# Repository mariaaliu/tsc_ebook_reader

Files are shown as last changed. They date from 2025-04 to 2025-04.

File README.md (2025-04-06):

## Aliu Maria-Denisa
#### 335CC
<br><br>

## Descriere generală
Acest proiect reprezintă un eBook Reader minimalist, denumit **OpenBook**, construit pe baza platformei **ESP32-C6** și echipat cu un ecran e-paper de **7.5 inch**, o baterie Li-Po, încărcare prin USB-C și butoane fizice pentru control.

Dispozitivul este proiectat să fie eficient energetic și ușor de utilizat, având o interfață simplă controlată prin GPIO-uri, cu funcții de afișare a textelor pentru o experiență de e-reading optimă.

---

<br><br>

## Cuprins
- [Specificații](#specificații)
- [Pași de implementare](#pași-de-implementare)
- [Diagramă Bloc](#diagramă-bloc)
- [BOM (Bill Of Materials)](#bom-bill-of-materials)
- [Descrierea hardware – Conexiuni și Funcționalitate](#descrierea-hardware--conexiuni-și-funcționalitate)
- [Pinout ESP32-C6](#pinout-esp32-c6)
- [Estimare Consum](#estimare-consum)
- [Vederi ale Prototipului](#vederi-ale-prototipului)

---

#### Specificații

- **MCU**: ESP32-C6 (Wi-Fi 6, BLE, RISC-V)
- **Ecran**: 7.8" E-paper
- **Stocare**: Slot microSD
- **Conectivitate**: Qwiic, USB-C
- **Senzori**: BME680 (temperatură, umiditate, gaz, presiune)
- **Alimentare**: Baterie Li-Po 3.7V, încărcare prin USB-C
- **RTC**: extern pentru consum redus în deep sleep
- **Control**: 3 butoane + LED

---
#### Pași de implementare:

- realizarea schemei electrice
- poziționarea pieselor pe PCB 2D
- realizarea modelului 3D
- simularea încadrării pieselor în carcasa finală
- prezentarea produsului final simulat
  
---

## Diagramă Bloc

```mermaid
graph TD;
    
    USB["USB-C Connector & ESD Protection"] -->|VBUS| CHG
    BATT["Li-Po Battery"] -->|VBAT| CHG["Battery Charging Controller (MCP73831)"]
    USB -->|VBUS pass-through| LDO["LDO Voltage Regulator (XC6220)"]
    USB -->|USB| ESP["ESP32-C6 MICROCONTROLLER Wi-Fi (MCU Central)"]
    CHG -->|VBAT| LDO
    LDO -->|3.3V| ESP["ESP32-C6 MICROCONTROLLER Wi-Fi (MCU Central)"]

    ESP -->|I2C| RTC["RTC Module (DS3231SN)"]
    ESP -->|I2C| BME["Environmental Sensor (BME680)"]

    ESP -->|SPI| FLASH["External NOR Flash (W25Q512)"]
    ESP -->|SPI| EPD_HEADER["E-Paper Display Header"]
    ESP -->|SPI| SD["MicroSD Card"]
    ESP -->|GPIO| BUTTONS["BOOT, CHANGE, RESET Buttons"]
    ESP -->|GPIO| VSUP["Voltage Supervisor + Reset/Boot IO"]

    EPD_HEADER -->|Power, SPI| EPD_DRIVER["E-Paper Drive Circuit"]
    EPD_DRIVER -->|Type Config| DISP_SEL["Display Type Selector"]
    EPD_DRIVER -->|High Voltage| EPD_POW["EPD Power Circuit"]

    I2C_CONN["Qwiic / Stemma QT"] -->|I2C| ESP
    BAT_LVL["Battery Charge Level"] -->|I2C| ESP
    SERCOM["RX/TX Serial Communication"] --> ESP
```

## BOM (Bill Of Materials)

| Componentă | Proptietăți | Package | Link Purchase | Datasheet | 
|---|---|---|---|---|
| BOOT_BUTTON | BUTTON_CUSYOMV1 | MYBUTTON | https://industry.panasonic.com/global/en/products/control/switch/light-touch/number/evqpuj02k | https://www.es.co.th/Schemetic/PDF/EVQPUX02K.PDF|
| C1 | 100nF | ESP32_WROVER_EAGLE-LTSPICE_C0402 | https://componentsearchengine.com/part-view/CC0402MRX5R5BB106/YAGEO | https://www.farnell.com/datasheets/2167237.pdf|
| C10 | 100nF | ESP32_WROVER_EAGLE-LTSPICE_C0402 | https://componentsearchengine.com/part-view/CC0402MRX5R5BB106/YAGEO | https://www.farnell.com/datasheets/2167237.pdf|
| C10_SUPERCAP | CPH3225A | CAPCP3225X100N  | https://www.snapeda.com/parts/CPH3225A/Seiko+Instruments/view-part/?ref=eda | https://www.eaton.com/content/dam/eaton/products/electronic-components/resources/data-sheet/eaton-xt-supercapacitors-cylindrical-cells-data-sheet.pdf|
| C1_BAT | 4.7uF | ESP32_WROVER_EAGLE-LTSPICE_C0402 | https://componentsearchengine.com/part-view/CC0402MRX5R5BB106/YAGEO | https://www.datasheets.com/part-details/ctc4-c-4-7uf-20--25v-exxelia-group-407015684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|
| C1_BAT1 | 4.7uF | ESP32_WROVER_EAGLE-LTSPICE_C0402 | https://componentsearchengine.com/part-view/CC0402MRX5R5BB106/YAGEO | https://www.datasheets.com/part-details/ctc4-c-4-7uf-20--25v-exxelia-group-407015684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|
| C1_BAT2 | 4.7uF | ESP32_WROVER_EAGLE-LTSPICE_C0402 | https://componentsearchengine.com/part-view/CC0402MRX5R5BB106/YAGEO | https://www.datasheets.com/part-details/ctc4-c-4-7uf-20--25v-exxelia-group-407015684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|
| C2 | 100nF | ESP32_WROVER_EAGLE-LTSPICE_C0402 | https://componentsearchengine.com/part-view/CC0402MRX5R5BB106/YAGEO | https://www.farnell.com/datasheets/2167237.pdf|
| C2_BAT | 4.7uF | ESP32_WROVER_EAGLE-LTSPICE_C0402 | https://componentsearchengine.com/part-view/CC0402MRX5R5BB106/YAGEO | https://www.datasheets.com/part-details/ctc4-c-4-7uf-20--25v-exxelia-group-407015684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|
| C3 | 100uF | RCL_CT3528 | https://eu.mouser.com/ProductDetail/KYOCERA-AVX/F910J107MBAAJ6?qs=PqoDHHvF649LraCA%2FjeGXg%3D%3D | https://www.farnell.com/datasheets/2167237.pdf|
| C4 | 4.7uF/25V | ESP32_WROVER_EAGLE-LTSPICE_C0402 | https://componentsearchengine.com/part-view/CC0402MRX5R5BB106/YAGEO | https://www.datasheets.com/part-details/ctc4-c-4-7uf-20--25v-exxelia-group-407015684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|
| C4_USB | 100nF | ESP32_WROVER_EAGLE-LTSPICE_C0402 | https://componentsearchengine.com/part-view/CC0402MRX5R5BB106/YAGEO | https://www.farnell.com/datasheets/2167237.pdf|
| C5 | 1uF | ESP32_WROVER_EAGLE-LTSPICE_C0402 | https://componentsearchengine.com/part-view/CC0402MRX5R5BB106/YAGEO | https://www.farnell.com/datasheets/2167237.pdf|
| C5_USB | 4.7uF | ESP32_WROVER_EAGLE-LTSPICE_C0402 | https://componentsearchengine.com/part-view/CC0402MRX5R5BB106/YAGEO | https://www.datasheets.com/part-details/ctc4-c-4-7uf-20--25v-exxelia-group-407015684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|
| C6 | 100nF | ESP32_WROVER_EAGLE-LTSPICE_C0402 | https://componentsearchengine.com/part-view/CC0402MRX5R5BB106/YAGEO | https://www.farnell.com/datasheets/2167237.pdf|
| C7 | 10uF | ESP32_WROVER_EAGLE-LTSPICE_C0402 | https://componentsearchengine.com/part-view/CC0402MRX5R5BB106/YAGEO | https://www.farnell.com/datasheets/2167237.pdf|
| C8 | 100nF | ESP32_WROVER_EAGLE-LTSPICE_C0402 | https://componentsearchengine.com/part-view/CC0402MRX5R5BB106/YAGEO | https://www.farnell.com/datasheets/2167237.pdf|
| C9 | 100nF | ESP32_WROVER_EAGLE-LTSPICE_C0402 | https://componentsearchengine.com/part-view/CC0402MRX5R5BB106/YAGEO | https://www.farnell.com/datasheets/2167237.pdf|
| CHANGE_BUTTON  | BUTTON_CUSYOMV1 | MYBUTTON | https://industry.panasonic.com/global/en/products/control/switch/light-touch/number/evqpuj02k | https://www.es.co.th/Schemetic/PDF/EVQPUX02K.PDF|
| CHG_LED | | ADAFRUIT_CHIP-LED0603 | https://www.snapeda.com/parts/KP-1608SURCK/Kingbright/view-part/?ref=search&t=LED%200603 | https://www.farnell.com/datasheets/1760130.pdf|
| C_DELAY | 100nF | ESP32_WROVER_EAGLE-LTSPICE_C0402 | https://componentsearchengine.com/part-view/CC0402MRX5R5BB106/YAGEO | https://www.farnell.com/datasheets/2167237.pdf|
| D1 | USBLC6-2SC6Y | SOT95P280X145-6N | https://www.snapeda.com/parts/USBLC6-2SC6Y/STMicroelectronics/view-part/?ref=eda | https://www.alldatasheet.com/view.jsp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|
| D10 | PGB1010603MR | DIOC1608X36N | https://www.snapeda.com/parts/PGB1010603MR/Littelfuse/view-part/?ref=eda | https://www.alldatasheet.com/view.jsp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|
| D11 | PGB1010603MR | DIOC1608X36N | https://www.snapeda.com/parts/PGB1010603MR/Littelfuse/view-part/?ref=eda | https://www.alldatasheet.com/view.jsp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|
| D12 | PGB1010603MR | DIOC1608X36N | https://www.snapeda.com/parts/PGB1010603MR/Littelfuse/view-part/?ref=eda | https://www.alldatasheet.com/view.jsp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|
| D2 | ESP32_WROVER_AVX---SD0805S020S1R0_AVX_SD0805S020S1R0_0 | ESP32_WROVER_AVX---SD0805S020S1R0_AVX_SD0805S020S1R0_0 | https://ro.mouser.com/ProductDetail/KYOCERA-AVX/SD0805S020S1R0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 | https://www.alldatasheet.com/datasheet-pdf/pdf/925781/AVX/SD0805S020S1R0.html|
| D3 | MBR0530 | SOD3716X135N | https://www.snapeda.com/parts/MBR0530/Onsemi/view-part/?ref=eda | https://www.alldatasheet.com/view.jsp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|
| D4 | MBR0530 | SOD3716X135N | https://www.snapeda.com/parts/MBR0530/Onsemi/view-part/?ref=eda | https://www.alldatasheet.com/view.jsp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|
| D5 | MBR0530 | SOD3716X135N | https://www.snapeda.com/parts/MBR0530/Onsemi/view-part/?ref=eda | https://www.alldatasheet.com/view.jsp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|
| D6 | PGB1010603MR | DIOC1608X36N | https://www.snapeda.com/parts/PGB1010603MR/Littelfuse/view-part/?ref=eda | https://www.alldatasheet.com/view.jsp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|
| D7 | ESP32_WROVER_AVX---SD0805S020S1R0_AVX_SD0805S020S1R0_0 | ESP32_WROVER_AVX---SD0805S020S1R0_AVX_SD0805S020S1R0_0 | https://eu.mouser.com/ProductDetail/KYOCERA-AVX/SD0805S020S1R0?qs=jCA%252BPfw4LHbpkAoSnwrdjw%3D%3D | https://www.alldatasheet.com/datasheet-pdf/pdf/925781/AVX/SD0805S020S1R0.html|
| D8 | PGB1010603MR | DIOC1608X36N | https://www.snapeda.com/parts/PGB1010603MR/Littelfuse/view-part/?ref=eda | https://www.alldatasheet.com/view.jsp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|
| D9 | PGB1010603MR | DIOC1608X36N | https://www.snapeda.com/parts/PGB1010603MR/Littelfuse/view-part/?ref=eda | https://www.alldatasheet.com/view.jsp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|
| EPD_C1 | 1uF/50V | ESP32_WROVER_EAGLE-LTSPICE_C0402 | https://componentsearchengine.com/part-view/CC0402MRX5R5BB106/YAGEO | https://www.alldatasheet.com/view.jsp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|
| EPD_C10 | 1uF/50V | ESP32_WROVER_EAGLE-LTSPICE_C0402 | https://componentsearchengine.com/part-view/CC0402MRX5R5BB106/YAGEO | https://www.alldatasheet.com/view.jsp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|
| EPD_C11 | 1uF/50V | ESP32_WROVER_EAGLE-LTSPICE_C0402 | https://componentsearchengine.com/part-view/CC0402MRX5R5BB106/YAGEO | https://www.farnell.com/datasheets/2167237.pdf|
| EPD_C12 | 1uF/50V | ESP32_WROVER_EAGLE-LTSPICE_C0402 | https://componentsearchengine.com/part-view/CC0402MRX5R5BB106/YAGEO | https://www.farnell.com/datasheets/2167237.pdf|
| EPD_C2 | 1uF/50V | ESP32_WROVER_EAGLE-LTSPICE_C0402 | https://componentsearchengine.com/part-view/CC0402MRX5R5BB106/YAGEO | https://www.farnell.com/datasheets/2167237.pdf|
| EPD_C5 | 1uF/50V | ESP32_WROVER_EAGLE-LTSPICE_C0402 | https://componentsearchengine.com/part-view/CC0402MRX5R5BB106/YAGEO | https://www.farnell.com/datasheets/2167237.pdf|
| EPD_C6 | 1uF/50V | ESP32_WROVER_EAGLE-LTSPICE_C0402 | https://componentsearchengine.com/part-view/CC0402MRX5R5BB106/YAGEO | https://www.farnell.com/datasheets/2167237.pdf|
| EPD_C7 | 1uF/50V | ESP32_WROVER_EAGLE-LTSPICE_C0402 | https://componentsearchengine.com/part-view/CC0402MRX5R5BB106/YAGEO | https://www.farnell.com/datasheets/2167237.pdf|
| EPD_C8 | 1uF/50V | ESP32_WROVER_EAGLE-LTSPICE_C0402 | https://componentsearchengine.com/part-view/CC0402MRX5R5BB106/YAGEO | https://www.farnell.com/datasheets/2167237.pdf|
| EPD_C9 | 1uF/50V | ESP32_WROVER_EAGLE-LTSPICE_C0402 | https://componentsearchengine.com/part-view/CC0402MRX5R5BB106/YAGEO | https://www.farnell.com/datasheets/2167237.pdf|
| IC1 | BD5229G-TR | SOT95P280X125-5N | https://componentsearchengine.com/part-view/BD5229G-TR/ROHM%20Semiconductor | https://www.alldatasheet.com/datasheet-pdf/pdf/562784/ROHM/BD5229G-TR.html|
| IC4 | XC6220A331MR-G | SOT95P280X120-5N | https://componentsearchengine.com/part-view/XC6220A331MR-G/Torex | https://www.alldatasheet.com/view.jsp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|
| J1 | FH34SRJ-24S-0.5SH_99_ | FH34SRJ24S05SH99 | https://componentsearchengine.com/part-view/FH34SRJ-24S-0.5SH(99)/Hirose | https://ro.mouser.com/ProductDetail/Hirose-Connector/FH34S-24S-05SH99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|
| J2 | SAMACSYS_PARTS_USB4110-GF-A | SAMACSYS_PARTS_USB4110GFA | https://componentsearchengine.com/part-view/USB4110-GF-A/GCT%20(GLOBAL%20CONNECTOR%20TECHNOLOGY) | https://www.lcsc.com/datasheet/lcsc_datasheet_2410121848_Global-Connector-Technology-USB4110-GF-A_C5143397.pdf|
| J3 | QWIIC_RIGHT_ANGLE | JST04_1MM_RA | https://eu.mouser.com/ProductDetail/Adafruit/4208?qs=PzGy0jfpSMtbScLbr0L5dw%3D%3D | ...|
| J4 | 112A-TAAR-R03_ATTEND | 112ATAARR03ATTEND | https://store.comet.srl.ro/Catalogue/Product/43497/ | https://www.lcsc.com/datasheet/lcsc_datasheet_2411220717_Attend-Technology-112A-TAAR-R03_C6970445.pdf|
| L1 | 68uH | IND_4828-WE-TPC_WRE | https://eu.mouser.com/ProductDetail/Wurth-Elektronik/744043680?qs=PGXP4M47uW6VkZq%252BkzjrHA%3D%3D | https://in.element14.com/c/passive-components/inductors/power-inductors/smd-power-inductors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|
| MCP73831  | ESP32_WROVER_SPARKFUN-IC-POWER_MCP73831 | ESP32_WROVER_SPARKFUN-IC-POWER_SOT23-5 | https://eu.mouser.com/ProductDetail/Microchip-Technology/MCP73831T-2ACI-OT?qs=yUQqVecv4qvbBQBGbHx0Mw%3D%3D | https://www.alldatasheet.com/view.jsp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|
| PFMF.050.1| ESP32C6_VARISTORCN1812 | ESP32C6_VARISTOR_CT/CN1812 | https://www.mouser.co.uk/ProductDetail/EPCOS-TDK/B72520T0350K062?qs=dEfas%2FXlABIszF52uu7vrg%3D%3D | https://www.alldatasheet.com/datasheet-pdf/pdf/356683/SCHURTER/PFMF.050.2.html|
| Q1 | 20V/4.2A/52mΩ/1.4W | ESP32_WROVER_SPARKFUN-DISCRETESEMI_SOT23-3 | https://componentsearchengine.com/part-view/DMG2305UX-7/Diodes%20Incorporated | https://www.alldatasheet.com/view.jsp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|
| Q2 | 20V/4.2A/52mΩ/1.4W | ESP32_WROVER_SPARKFUN-DISCRETESEMI_SOT23-3 | https://componentsearchengine.com/part-view/DMG2305UX-7/Diodes%20Incorporated | https://www.alldatasheet.com/view.jsp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|
| Q3 | SI1308EDL-T1-GE3 | SOT65P210X110-3N | https://www.snapeda.com/parts/SI1308EDL-T1-GE3/Vishay+Siliconix/view-part/?ref=eda | https://www.alldatasheet.com/view.jsp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|
| R1 | 10K | ESP32_WROVER_EAGLE-LTSPICE_R0402 | https://componentsearchengine.com/part-view/R0402%201%25%20100%20K%20(RC0402FR-07100KL)/YAGEO | https://ro.farnell.com/c/passive-components/resistors-fixed-value/chip-smd-resistors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|
| R10 | 10K | ESP32_WROVER_EAGLE-LTSPICE_R0402 | https://componentsearchengine.com/part-view/R0402%201%25%20100%20K%20(RC0402FR-07100KL)/YAGEO | https://ro.farnell.com/c/passive-components/resistors-fixed-value/chip-smd-resistors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|
| R1_BAT | 200 | ESP32_WROVER_EAGLE-LTSPICE_R0402 | https://ro.mouser.com/c/passive-components/resistors/smd-resistors-chip-resistors/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 | https://www.farnell.com/datasheets/2167237.pdf|
| R1_PINH | 10K | ESP32_WROVER_EAGLE-LTSPICE_R0402 | https://componentsearchengine.com/part-view/R0402%201%25%20100%20K%20(RC0402FR-07100KL)/YAGEO | https://ro.farnell.com/c/passive-components/resistors-fixed-value/chip-smd-resistors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|
| R1_PINH1  | 10K | ESP32_WROVER_EAGLE-LTSPICE_R0402 | https://componentsearchengine.com/part-view/R0402%201%25%20100%20K%20(RC0402FR-07100KL)/YAGEO | https://ro.farnell.com/c/passive-components/resistors-fixed-value/chip-smd-resistors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|
| R1_PWRUSB | 100k | ESP32_WROVER_EAGLE-LTSPICE_R0402 | https://componentsearchengine.com/part-view/R0402%201%25%20100%20K%20(RC0402FR-07100KL)/YAGEO | https://ro.farnell.com/c/passive-components/resistors-fixed-value/chip-smd-resistors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|
| R2 | 2.2 | ESP32_WROVER_EAGLE-LTSPICE_R0402 | https://componentsearchengine.com/part-view/R0402%201%25%20100%20K%20(RC0402FR-07100KL)/YAGEO | https://ro.farnell.com/c/passive-components/resistors-fixed-value/chip-smd-resistors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|
| R2-PINH | 10K | ESP32_WROVER_EAGLE-LTSPICE_R0402 | https://componentsearchengine.com/part-view/R0402%201%25%20100%20K%20(RC0402FR-07100KL)/YAGEO |
| R2-USB | 5k1 | ESP32_WROVER_EAGLE-LTSPICE_R0402 | https://componentsearchengine.com/part-view/R0402%201%25%20100%20K%20(RC0402FR-07100KL)/YAGEO | https://ro.farnell.com/c/passive-components/resistors-fixed-value/chip-smd-resistors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|
| R2-USB1 | 5k1 | ESP32_WROVER_EAGLE-LTSPICE_R0402 | https://componentsearchengine.com/part-view/R0402%201%25%20100%20K%20(RC0402FR-07100KL)/YAGEO | https://ro.farnell.com/c/passive-components/resistors-fixed-value/chip-smd-resistors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|
| R2_BAT | 2K | ESP32_WROVER_EAGLE-LTSPICE_R0402 | https://componentsearchengine.com/part-view/R0402%201%25%20100%20K%20(RC0402FR-07100KL)/YAGEO |https://ro.farnell.com/c/passive-components/resistors-fixed-value/chip-smd-resistors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|
| R2_PINH1  | 10K | ESP32_WROVER_EAGLE-LTSPICE_R0402 | https://componentsearchengine.com/part-view/R0402%201%25%20100%20K%20(RC0402FR-07100KL)/YAGEO | https://ro.farnell.com/c/passive-components/resistors-fixed-value/chip-smd-resistors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|
| R3 | 0.47 | ESP32_WROVER_EAGLE-LTSPICE_R0402 | https://componentsearchengine.com/part-view/R0402%201%25%20100%20K%20(RC0402FR-07100KL)/YAGEO |https://ro.farnell.com/c/passive-components/resistors-fixed-value/chip-smd-resistors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|
| R4 | 10K | ESP32_WROVER_EAGLE-LTSPICE_R0402 | https://componentsearchengine.com/part-view/R0402%201%25%20100%20K%20(RC0402FR-07100KL)/YAGEO |https://ro.farnell.com/c/passive-components/resistors-fixed-value/chip-smd-resistors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|
| R5 | 10K | ESP32_WROVER_EAGLE-LTSPICE_R0402 | https://componentsearchengine.com/part-view/R0402%201%25%20100%20K%20(RC0402FR-07100KL)/YAGEO |https://ro.farnell.com/c/passive-components/resistors-fixed-value/chip-smd-resistors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|
| R6 | 10K | ESP32_WROVER_EAGLE-LTSPICE_R0402 | https://componentsearchengine.com/part-view/R0402%201%25%20100%20K%20(RC0402FR-07100KL)/YAGEO | https://ro.farnell.com/c/passive-components/resistors-fixed-value/chip-smd-resistors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|
| R7 | 10K | ESP32_WROVER_EAGLE-LTSPICE_R0402 | https://componentsearchengine.com/part-view/R0402%201%25%20100%20K%20(RC0402FR-07100KL)/YAGEO |https://ro.farnell.com/c/passive-components/resistors-fixed-value/chip-smd-resistors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|
| R8 | 10K | ESP32_WROVER_EAGLE-LTSPICE_R0402 | https://componentsearchengine.com/part-view/R0402%201%25%20100%20K%20(RC0402FR-07100KL)/YAGEO |https://ro.farnell.com/c/passive-components/resistors-fixed-value/chip-smd-resistors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|
| R9 | 10K | ESP32_WROVER_EAGLE-LTSPICE_R0402 | https://componentsearchengine.com/part-view/R0402%201%25%20100%20K%20(RC0402FR-07100KL)/YAGEO |https://ro.farnell.com/c/passive-components/resistors-fixed-value/chip-smd-resistors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|
| RESET_BUTTON  | BUTTON_CUSYOMV1  | MYBUTTON | https://industry.panasonic.com/global/en/products/control/switch/light-touch/number/evqpuj02k | https://www.es.co.th/Schemetic/PDF/EVQPUX02K.PDF|
| R_BOOT | 10K | ESP32_WROVER_EAGLE-LTSPICE_R0402 | https://componentsearchengine.com/part-view/R0402%201%25%20100%20K%20(RC0402FR-07100KL)/YAGEO | https://ro.farnell.com/c/passive-components/resistors-fixed-value/chip-smd-resistors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|
| R_CAPACITOR | 15 | ESP32_WROVER_EAGLE-LTSPICE_R0402 | https://componentsearchengine.com/part-view/R0402%201%25%20100%20K%20(RC0402FR-07100KL)/YAGEO | https://ro.farnell.com/c/passive-components/resistors-fixed-value/chip-smd-resistors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|
| R_CHANGE  | 10K | ESP32_WROVER_EAGLE-LTSPICE_R0402 | https://componentsearchengine.com/part-view/R0402%201%25%20100%20K%20(RC0402FR-07100KL)/YAGEO | https://ro.farnell.com/c/passive-components/resistors-fixed-value/chip-smd-resistors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|
| R_CL1 | 10K | ESP32_WROVER_EAGLE-LTSPICE_R0402 | https://componentsearchengine.com/part-view/R0402%201%25%20100%20K%20(RC0402FR-07100KL)/YAGEO | https://ro.farnell.com/c/passive-components/resistors-fixed-value/chip-smd-resistors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|
| R_RESET | 10K | ESP32_WROVER_EAGLE-LTSPICE_R0402 | https://componentsearchengine.com/part-view/R0402%201%25%20100%20K%20(RC0402FR-07100KL)/YAGEO | https://ro.farnell.com/c/passive-components/resistors-fixed-value/chip-smd-resistors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|
| SENSOR2 | ESP32_WROVER_BME680_BME680 | ESP32_WROVER_BME680_PSON80P300X300X100-8N | https://www.snapeda.com/parts/BME680/Bosch/view-part/?welcome=home | https://www.bosch-sensortec.com/media/boschsensortec/downloads/datasheets/bst-bme680-ds001.pdf|
| SJ1 | | SJ | https://grabcad.com/library/solder-jumpers-1 |...|
| TP1 | TPTP20R | TP20R | CUSTOM
| TP10 | TPTP20R | TP20R | CUSTOM
| TP11 | TPTP20R | TP20R | CUSTOM
| TP12 | TPTP20R | TP20R | CUSTOM
| TP13 | TPTP20R | TP20R | CUSTOM
| TP14 | TPTP20R | TP20R | CUSTOM
| TP15 | TPTP20R | TP20R | CUSTOM
| TP16 | TPTP20R | TP20R | CUSTOM
| TP17 | TPTP20R | TP20R | CUSTOM
| TP2 | TPTP20R | TP20R | CUSTOM
| TP3 | TPTP20R | TP20R | CUSTOM
| TP4 | TPTP20R | TP20R | CUSTOM
| TP5 | TPTP20R | TP20R | CUSTOM
| TP6 | TPTP20R | TP20R | CUSTOM
| TP7 | TPTP20R | TP20R | CUSTOM
| TP8 | TPTP20R | TP20R | CUSTOM
| TP9 | TPTP20R | TP20R | CUSTOM
| U5 | W25Q512JVEIQ | SON127P600X800X80-9N | https://www.snapeda.com/parts/W25Q512JVEIQ/Winbond+Electronics/view-part/?ref=eda | https://www.alldatasheet.com/view.jsp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|
| U2 | ESP32-C6-WROOM-1-N8 | XCVR_ESP32-C6-WROOM-1-N8 | https://www.snapeda.com/parts/ESP32-C6-WROOM-1-N8/Espressif+Systems/view-part/?ref=eda | https://www.espressif.com/sites/default/files/documentation/esp32-c6-wroom-1_wroom-1u_datasheet_en.pdf|
| U3 | DS3231SN# | SOIC127P1032X265-16N | https://www.snapeda.com/parts/DS3231SN%23/Analog+Devices/view-part/?ref=eda |https://www.mouser.com/datasheet/2/472/si864x_datasheet-2507790.pdf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|
| U4 | MAX17048G+T10 | SON50P200X200X80-9N | https://www.snapeda.com/parts/MAX17048G+T10/Analog+Devices/view-part/?ref=eda | https://www.alldatasheet.com/view.jsp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|

<br><br>
<br><br>

## Descrierea hardware – Conexiuni și Funcționalitate

---

### USB-C Connector & ESD Protection
- **Protocol:** USB 2.0 + VBUS alimentare  
- **Conectat la:** MCP73831 (încărcare baterie), ESP32-C6 (USB)  
- **Rol:** Permite programarea ESP-ului și încărcarea bateriei prin VBUS.  
- **Pini ESP32-C6:** `IO13` (USB_D-), `IO14` (USB_D+)

---

### Li-Po Battery + MCP73831 (Battery Charging Controller)
- **Protocol:** Analog / GPIO  
- **Conectat la:** MCP73831 → LDO → ESP32-C6  
- **Rol:** Gestionează încărcarea bateriei și alimentează întregul sistem.  
- **Status LED:** `IO4` controlează CHG LED-ul pentru stare încărcare.

---

### XC6220 (LDO Voltage Regulator)
- **Protocol:** Analog (power rail)  
- **Conectat la:** MCP73831 (VBAT in) → ESP32-C6 (3.3V out)  
- **Rol:** Asigură tensiunea stabilă de 3.3V pentru toate componentele digitale.

---

### W25Q512 (External NOR Flash)
- **Protocol:** SPI  
- **Conectat la ESP32-C6:**  
  - `IO6` – SCK  
  - `IO7` – MOSI  
  - `IO2` – MISO  
  - `IO12` – CS  
- **Rol:** Memorie externă pentru date persistente.

---

### E-Paper Display Header & Driver
- **Protocol:** SPI + GPIO  
- **Conectat la ESP32-C6:**  
  - `IO6` – SCK  
  - `IO7` – MOSI  
  - `IO2` – MISO  
  - `IO10` – CS  
  - `IO5` – DC  
  - `IO14` – BUSY  
  - `IO21` – RST  
- **Rol:** Afișaj de tip e-paper controlat prin SPI, cu semnale suplimentare pentru control de stare.

---

### MicroSD Card
- **Protocol:** SPI (partajat)  
- **Conectat la ESP32-C6:**  
  - `IO4` – CS_SD  
  - SPI pinii partajați: `IO6`, `IO7`, `IO2`  
- **Rol:** Stocare de fișiere externe (texte, resurse).

---

### RTC DS3231SN
- **Protocol:** I²C + GPIO  
- **Conectat la ESP32-C6:**  
  - `IO19` – SDA  
  - `IO20` – SCL  
  - `IO0` – INT_RTC  
  - `IO17` – RTC_RST  
- **Rol:** Timp real precis, chiar și în sleep. Suportă trezire automată.

---

### BME680 – Environmental Sensor
- **Protocol:** I²C (partajat cu RTC)  
- **Conectat la ESP32-C6:**  
  - `IO19` – SDA  
  - `IO20` – SCL  
- **Rol:** Măsoară temperatura, presiunea, umiditatea și calitatea aerului.

---

### Butoane de control (BOOT, CHANGE, RESET)
- **Protocol:** GPIO  
- **Conectat la ESP32-C6:**  
  - `IO15` – BOOT  
  - `IO3` – RESET  
  - `IO23` – CHANGE  
- **Rol:** Interacțiune fizică pentru utilizator (navigare, programare, resetare).

---

### Voltage Supervisor & IO
- **Protocol:** GPIO  
- **Conectat la ESP32-C6:** `IO1`, `IO18`, `IO22`  
- **Rol:** Supraveghează tensiunile critice și oferă siguranță în boot/reset.

---

### Battery Level Monitor
- **Protocol:** ADC  
- **Conectat la ESP32-C6:** `IO18`  
- **Rol:** Măsoară nivelul de tensiune al bateriei pentru notificări/logare.

---

### Qwiic / Stemma QT Connector
- **Protocol:** I²C (extensie)  
- **Conectat la ESP32-C6:**  
  - `IO19` – SDA  
  - `IO20` – SCL  
- **Rol:** Permite adăugarea de senzori/modul I²C externi fără lipire.

---

### Serial (TX/RX)
- **Protocol:** UART  
- **Conectat la ESP32-C6:**  
  - `IO25` – TX  
  - `IO24` – RX  
---

<br><br>
<br><br>

# Pinout ESP32-C6

#### IO2 – MISO (SPI)
- **Utilizat de:** Flash NOR, E-Paper, microSD
- **Motiv:** Este un pin hardware dedicat SPI pe ESP32-C6, oferind viteză și compatibilitate nativă.

#### IO6 – SCK (SPI Clock)
- **Utilizat de:** Flash NOR, E-Paper, microSD
- **Motiv:** Este pinul recomandat pentru ceasul SPI în implementări multiple. Permite partajarea magistralei.

#### IO7 – MOSI (SPI Data Out)
- **Utilizat de:** Flash NOR, E-Paper, microSD
- **Motiv:** Folosit pentru transmiterea datelor SPI, compatibil cu toți perifericii SPI conectați.

#### IO4 – CS_SD
- **Utilizat de:** microSD Card
- **Motiv:** Selectează SD cardul când se face citirea. Ales pentru a nu intra în conflict cu ceilalți CS deja folosiți.

#### IO12 – CS Flash
- **Utilizat de:** Memorie NOR Flash
- **Motiv:** Pin dedicat pentru activarea memoriei Flash externă, fără a perturba alte periferice SPI.

#### IO10 – CS EPD
- **Utilizat de:** E-Paper Display
- **Motiv:** Selectează afișajul în timpul transferului SPI. Nu interferează cu restul SPI.

#### IO5 – DC (Data/Command pentru EPD)
- **Utilizat de:** E-Paper Display
- **Motiv:** Semnal de control specific EPD pentru diferențierea între comenzi și date.

#### IO14 – EPD_BUSY
- **Utilizat de:** E-Paper Display
- **Motiv:** Semnal GPIO de stare trimis de driver-ul EPD. ESP32 citește dacă ecranul este ocupat.

#### IO21 – EPD_RST
- **Utilizat de:** E-Paper Display
- **Motiv:** Resetează circuitul EPD înainte de inițializare sau afișare.

#### IO19 – SDA (I²C)
- **Utilizat de:** RTC, BME680, Qwiic
- **Motiv:** Magistrală de date pentru comunicare I²C. Este partajabil între mai mulți senzori.

#### IO20 – SCL (I²C)
- **Utilizat de:** RTC, BME680, Qwiic
- **Motiv:** Linie de ceas I²C. Se sincronizează cu SDA pentru transmisie fiabilă.

#### IO0 – INT RTC
- **Utilizat de:** RTC
- **Motiv:** Semnal de întrerupere care poate trezi ESP-ul din deep sleep.

#### IO17 – RTC Reset
- **Utilizat de:** RTC
- **Motiv:** Reset manual extern al RTC, util pentru sincronizări inițiale sau watchdog.

#### IO15 – BOOT
- **Utilizat de:** Buton BOOT
- **Motiv:** Este pinul standard pentru intrarea în modul de programare ESP32-C6.

#### IO3 – RESET
- **Utilizat de:** Buton RESET
- **Motiv:** Legat la EN pin intern, permite restartarea manuală a microcontrollerului.

#### IO23 – Buton CHANGE
- **Utilizat de:** Navigare interfață
- **Motiv:** GPIO general ales pentru acțiuni definite de utilizator (ex: Next Page).

#### IO25/IO24 – UART TX/RX
- **Utilizat de:** Debug Serial
- **Motiv:** Conexiune standard UART. Permite comunicarea cu un PC sau terminal serial.

#### IO18 – Battery Monitor
- **Utilizat de:** Măsurare baterie (ADC)
- **Motiv:** ESP32-C6 permite conversie ADC pe acest pin, ideal pentru a detecta nivelul bateriei.

---

## Estimare Consum

| Modul | Consum (mediu) | Activ/Idle |
|---|---|---|
| ESP32-C6 | ~80 mA | 130 mA / 12 µA (deep sleep) |
| E-paper 7.8” | ~26 mA la refresh | 0 mA idle |
| BME680 | ~2.1 mA | 0.15 mA standby |
| microSD card (active) | ~30-100 mA | 0.1 mA sleep |
| RTC + supercap | ~1 µA | |
| LED | max ~10 mA | doar la activare |
| **Total estimat** | ~100-150 mA (medie activă) | ~15 µA (deep sleep) |

Cu o baterie de 1200 mAh, durata estimată:
- **Utilizare activă (ocazional refresh)**: 8–10h
- **Deep sleep majoritar**: până la 300 zile standby

---

## Vederi ale Prototipului

### Ecran e-paper 7.8” integrat în carcasă
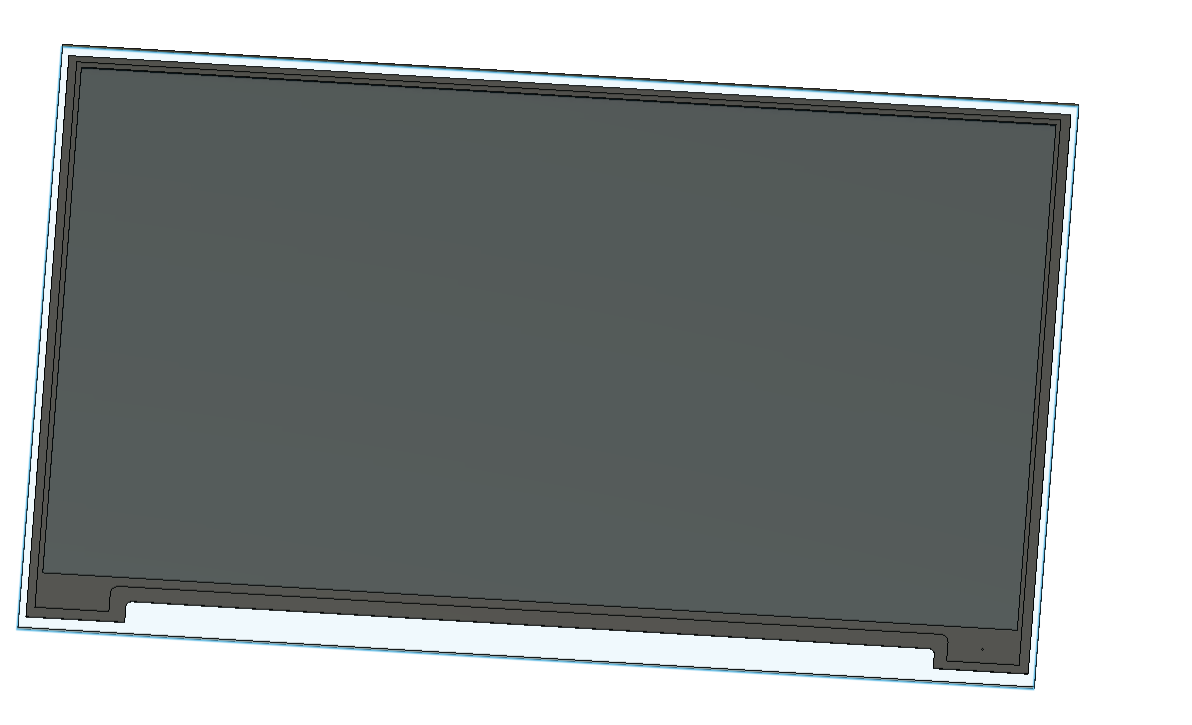
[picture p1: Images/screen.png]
Ecran e-paper


### PCB – Top View
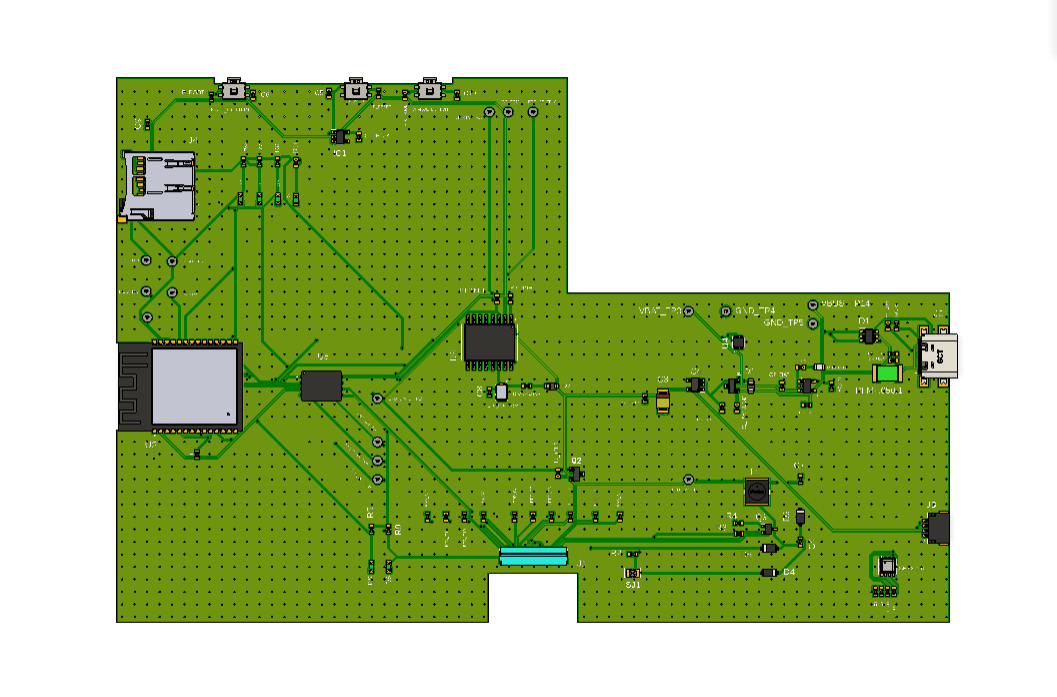
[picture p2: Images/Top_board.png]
Top PCB


### PCB – Bottom View
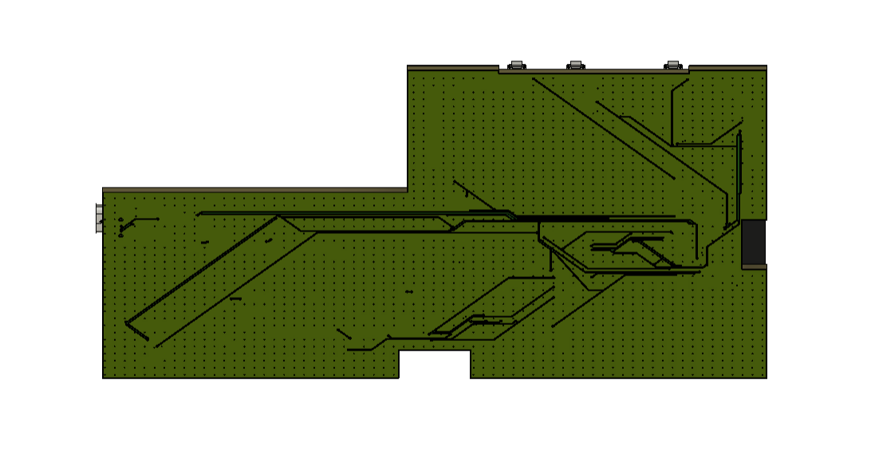
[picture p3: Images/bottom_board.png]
Bottom PCB


### Asamblare completă
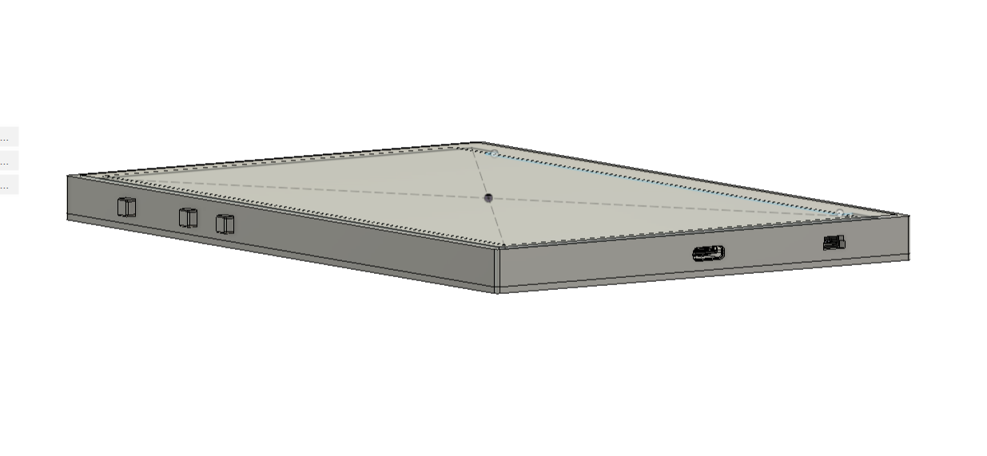
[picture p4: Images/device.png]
Dispozitiv complet – vedere


### Spate carcasă + porturi
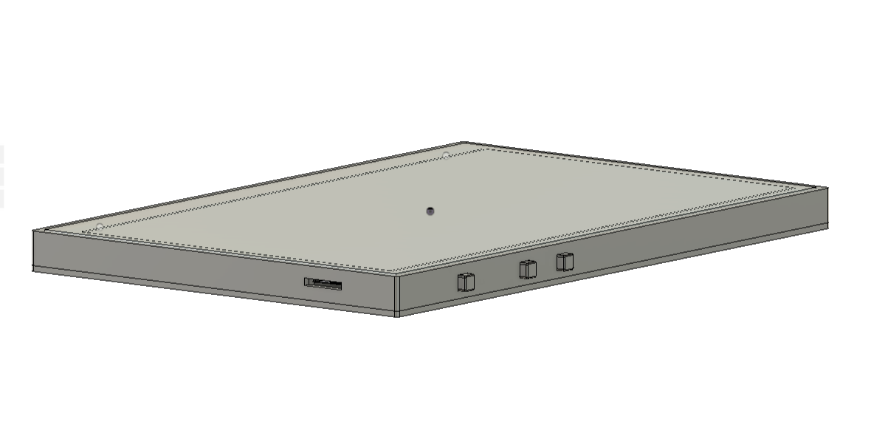
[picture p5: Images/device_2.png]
Spate carcasă


### Întreg ansamblu în carcasă – vedere explodată
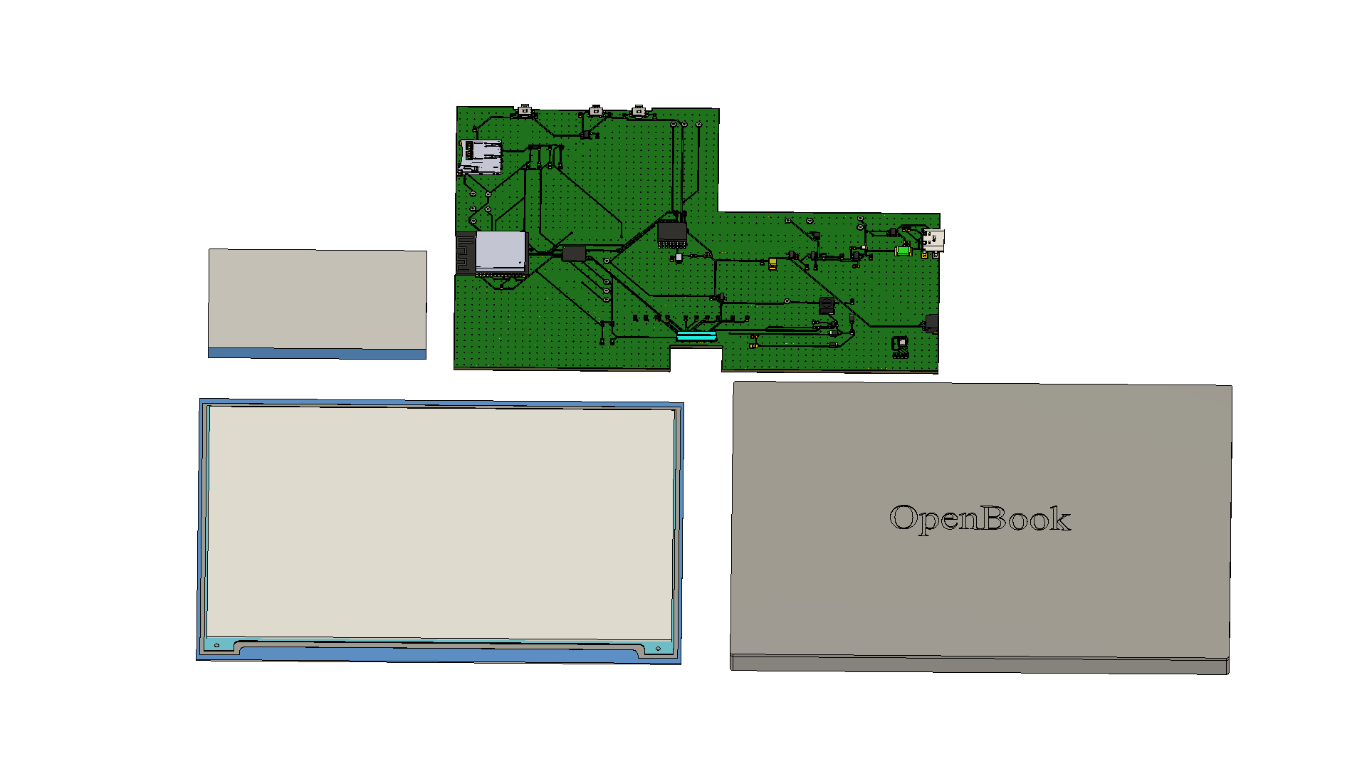
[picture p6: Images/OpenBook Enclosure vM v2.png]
Explodat + carcasă


### Vedere isometrică – 2/3
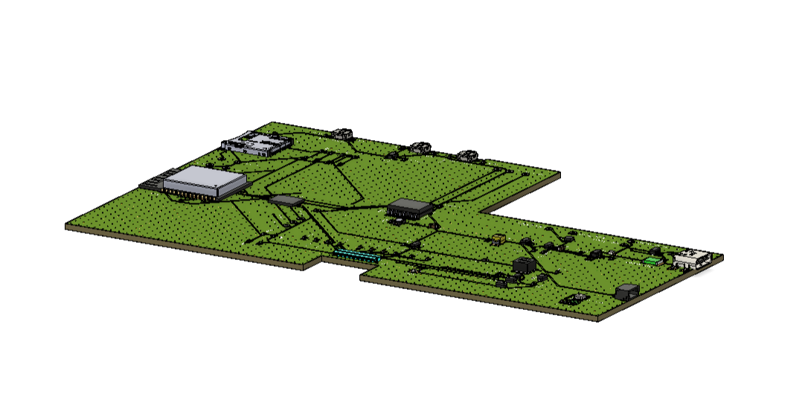
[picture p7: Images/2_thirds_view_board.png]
2/3 View


### Vedere isometrică – 2/3 (flipped)
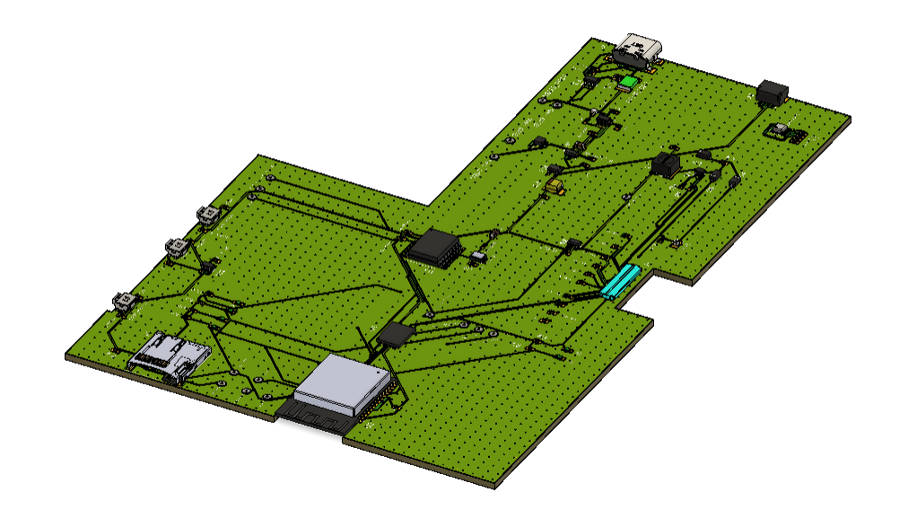
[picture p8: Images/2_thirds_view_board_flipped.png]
2/3 View Flipped


---

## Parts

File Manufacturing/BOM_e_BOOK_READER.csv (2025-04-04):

Qty | Value | Device | Package | Parts | Description | ARROW_PART_NUMBER | ARROW_PRICE-STOCK | AVAILABILITY | CENTROID_NOT_SPECIFIED | CHECK_PRICES | COPYRIGHT | DATASHEET | DESCRIPTION | DIGIKEY_DESCRIPTION | DIGIKEY_PART_NUMBER | HEIGHT | LEAD_FREE | MANUFACTURER_NAME | MANUFACTURER_PART_NUMBER | MF | MFR_NAME | MOUSER_PART_NUMBER | MOUSER_PRICE-STOCK | MOUSER_TESTING_PART_NUMBER | MOUSER_TESTING_PRICE-STOCK | MP | MPN | PACKAGE | POPULARITY | PREFIX | PRICE | PROD_ID | PURCHASE-URL | ROHS | SNAPEDA_LINK | SPICEMODEL | SPICEPREFIX | TEMPERATURE_RANGE_HIGH | TEMPERATURE_RANGE_LOW | TP_SIGNAL_NAME | VALUE
1 |  | ADAFRUIT_LEDCHIP-LED0603 | ADAFRUIT_CHIP-LED0603 | CHG_LED | LED
1 |  | SJ | SJ | SJ1 | SMD solder JUMPER |  |  |  |  |  |  |  |  |  |  |  |  |  |  |  |  |  |  |  |  |  |  |  | 3
1 | 0.1uF/50V | ESP32_WROVER_EAGLE-LTSPICE_CC0402 | ESP32_WROVER_EAGLE-LTSPICE_C0402 | EPD_C5 | CAPACITOR, European symbol |  |  |  |  |  |  |  |  |  |  |  |  |  |  |  |  |  |  |  |  |  |  |  |  |  |  |  |  |  |  | NONE | C
1 | 0.47 | ESP32_WROVER_EAGLE-LTSPICE_RR0402 | ESP32_WROVER_EAGLE-LTSPICE_R0402 | R3 | RESISTOR, European symbol |  |  |  |  |  |  |  |  |  |  |  |  |  |  |  |  |  |  |  |  |  |  |  |  |  |  |  |  |  |  | NONE | R
1 | 100K | ESP32_WROVER_EAGLE-LTSPICE_RR0402 | ESP32_WROVER_EAGLE-LTSPICE_R0402 | R1_PWRUSB | RESISTOR, European symbol |  |  |  |  |  |  |  |  |  |  |  |  |  |  |  |  |  |  |  |  |  |  |  |  |  |  |  |  |  |  | NONE | R
8 | 100nF | ESP32_WROVER_EAGLE-LTSPICE_CC0402 | ESP32_WROVER_EAGLE-LTSPICE_C0402 | C1, C2, C4_USB, C6, C8, C9, C10, C_DELAY | CAPACITOR, European symbol |  |  |  |  |  |  |  |  |  |  |  |  |  |  |  |  |  |  |  |  |  |  |  |  |  |  |  |  |  |  | NONE | C
1 | 100uF | RCL_CPOL-EUCT3528 | RCL_CT3528 | C3 | POLARIZED CAPACITOR, European symbol |  |  |  |  |  |  |  |  |  |  |  |  |  |  |  |  |  |  |  |  |  |  |  | 0 |  |  |  |  |  |  |  | C
15 | 10K | ESP32_WROVER_EAGLE-LTSPICE_RR0402 | ESP32_WROVER_EAGLE-LTSPICE_R0402 | R1, R1-PINH, R1-PINH1, R2-PINH, R2-PINH1, R4, R5, R6, R7, R8, R9, R10, R_BOOT, R_CHANGE, R_RESET | RESISTOR, European symbol |  |  |  |  |  |  |  |  |  |  |  |  |  |  |  |  |  |  |  |  |  |  |  |  |  |  |  |  |  |  | NONE | R
1 | 10k | ESP32_WROVER_EAGLE-LTSPICE_RR0402 | ESP32_WROVER_EAGLE-LTSPICE_R0402 | R_CL1 | RESISTOR, European symbol |  |  |  |  |  |  |  |  |  |  |  |  |  |  |  |  |  |  |  |  |  |  |  |  |  |  |  |  |  |  | NONE | R
1 | 10uF | ESP32_WROVER_EAGLE-LTSPICE_CC0402 | ESP32_WROVER_EAGLE-LTSPICE_C0402 | C7 | CAPACITOR, European symbol |  |  |  |  |  |  |  |  |  |  |  |  |  |  |  |  |  |  |  |  |  |  |  |  |  |  |  |  |  |  | NONE | C
1 | 112A-TAAR-R03_ATTEND | 112A-TAAR-R03_ATTEND | 112ATAARR03ATTEND | J4 | Micro SD Card Socket, Push-Push Type, Top Mount, SMT, H=1.83mm, 10u |  |  |  |  |  |  |  | Micro SD Card Socket | Push-Push Type | Top Mount | SMT | H=1.83mm | 10u |  |  | 1.9mm |  | ATTEND | 112A-TAAR-R03 ATTEND
1 | 15 | ESP32_WROVER_EAGLE-LTSPICE_RR0402 | ESP32_WROVER_EAGLE-LTSPICE_R0402 | R_CAPACITOR | RESISTOR, European symbol |  |  |  |  |  |  |  |  |  |  |  |  |  |  |  |  |  |  |  |  |  |  |  |  |  |  |  |  |  |  | NONE | R
1 | 1uF | ESP32_WROVER_EAGLE-LTSPICE_CC0402 | ESP32_WROVER_EAGLE-LTSPICE_C0402 | C5 | CAPACITOR, European symbol |  |  |  |  |  |  |  |  |  |  |  |  |  |  |  |  |  |  |  |  |  |  |  |  |  |  |  |  |  |  | NONE | C
9 | 1uF/50V | ESP32_WROVER_EAGLE-LTSPICE_CC0402 | ESP32_WROVER_EAGLE-LTSPICE_C0402 | EPD_C1, EPD_C2, EPD_C6, EPD_C7, EPD_C8, EPD_C9, EPD_C10, EPD_C11, EPD_C12 | CAPACITOR, European symbol |  |  |  |  |  |  |  |  |  |  |  |  |  |  |  |  |  |  |  |  |  |  |  |  |  |  |  |  |  |  | NONE | C
1 | 2.2 | ESP32_WROVER_EAGLE-LTSPICE_RR0402 | ESP32_WROVER_EAGLE-LTSPICE_R0402 | R2 | RESISTOR, European symbol |  |  |  |  |  |  |  |  |  |  |  |  |  |  |  |  |  |  |  |  |  |  |  |  |  |  |  |  |  |  | NONE | R
1 | 200 | ESP32_WROVER_EAGLE-LTSPICE_RR0402 | ESP32_WROVER_EAGLE-LTSPICE_R0402 | R1_BAT | RESISTOR, European symbol |  |  |  |  |  |  |  |  |  |  |  |  |  |  |  |  |  |  |  |  |  |  |  |  |  |  |  |  |  |  | NONE | R
2 | 20V/4.2A/52mO/1.4W | ESP32_WROVER_SPARKFUN-DISCRETESEMI_MOSFET_PCH-DMG2305UX-7 | ESP32_WROVER_SPARKFUN-DISCRETESEMI_SOT23-3 | Q1, Q2 | P-channel MOSFETs |  |  |  |  |  |  |  |  |  |  |  |  |  |  |  |  |  |  |  |  |  |  |  |  |  |  | TRAN-14388 |  |  |  |  |  |  |  |  | 20V/4.2A/52mO/1.4W
1 | 2K | ESP32_WROVER_EAGLE-LTSPICE_RR0402 | ESP32_WROVER_EAGLE-LTSPICE_R0402 | R2_BAT | RESISTOR, European symbol |  |  |  |  |  |  |  |  |  |  |  |  |  |  |  |  |  |  |  |  |  |  |  |  |  |  |  |  |  |  | NONE | R
5 | 4.7uF | ESP32_WROVER_EAGLE-LTSPICE_CC0402 | ESP32_WROVER_EAGLE-LTSPICE_C0402 | C1_BAT, C1_BAT1, C1_BAT2, C2_BAT, C5_USB | CAPACITOR, European symbol |  |  |  |  |  |  |  |  |  |  |  |  |  |  |  |  |  |  |  |  |  |  |  |  |  |  |  |  |  |  | NONE | C
1 | 4.7uF/25V | ESP32_WROVER_EAGLE-LTSPICE_CC0402 | ESP32_WROVER_EAGLE-LTSPICE_C0402 | C4 | CAPACITOR, European symbol |  |  |  |  |  |  |  |  |  |  |  |  |  |  |  |  |  |  |  |  |  |  |  |  |  |  |  |  |  |  | NONE | C
1 | 5K1 | ESP32_WROVER_EAGLE-LTSPICE_RR0402 | ESP32_WROVER_EAGLE-LTSPICE_R0402 | R2-USB | RESISTOR, European symbol |  |  |  |  |  |  |  |  |  |  |  |  |  |  |  |  |  |  |  |  |  |  |  |  |  |  |  |  |  |  | NONE | R
1 | 5k1 | ESP32_WROVER_EAGLE-LTSPICE_RR0402 | ESP32_WROVER_EAGLE-LTSPICE_R0402 | R2-USB1 | RESISTOR, European symbol |  |  |  |  |  |  |  |  |  |  |  |  |  |  |  |  |  |  |  |  |  |  |  |  |  |  |  |  |  |  | NONE | R
1 | 68uH | 744043680IND_4828-WE-TPC_WRE | IND_4828-WE-TPC_WRE | L1 |  |  |  |  |  |  | Copyright (C) 2024 Ultra Librarian. All rights reserved. |  |  |  |  |  |  |  | 744043680 |  | Wurth Electronics
1 | BD5229G-TR | BD5229G-TR | SOT95P280X125-5N | IC1 | Voltage Detector with Adjustable Delay Time: CMOS processes are utilized to develop high precision, low current consumption CMOS reset ICs that allow arbitrary setting of the delay time. The extensive lineup includes both Nch Open Drain and CMOS output types in a wide range of detection voltages (from 2.3V to 6.0V, in 0.1V steps), enabling selection of the ideal solution based on customer requirements. In addition, the entire series is of course both lead-free and RoHS-compliant. |  |  |  |  |  |  |  | Voltage Detector with Adjustable Delay Time: CMOS processes are utilized to develop high precision | low current consumption CMOS reset ICs that allow arbitrary setting of the delay time. The extensive lineup includes both Nch Open Drain and CMOS output types in a wide range of detection voltages (from 2.3V to 6.0V | in 0.1V steps) | enabling selection of the ideal solution based on customer requirements. In addition | the entire series is of course both lead-free and RoHS-compliant. |  |  | 1.25mm |  | ROHM Semiconductor | BD5229G-TR |  |  | 755-BD5229G-TR | https://www.mouser.co.uk/ProductDetail/ROHM-Semiconductor/BD5229G-TR?qs=4kLU8WoGk0vvnhrrYwdszw%3D%3D
3 | BUTTON_CUSYOMV1 | BUTTON_CUSYOMV1 | MYBUTTON | BOOT_BUTTON, CHANGE_BUTTON, RESET_BUTTON
1 | CPH3225A | CPH3225A | CAPCP3225X100N | C10_SUPERCAP | Cap 0.011F 3.3V 1210 Flat Check availability |  |  | Not in stock |  | https://www.snapeda.com/parts/CPH3225A/Seiko+Instruments/view-part/?ref=eda |  |  | 11 mF (EDLC) Supercapacitor 3.3 V 1210 (3225 Metric) - - |  |  |  |  |  |  | Seiko Instruments |  |  |  |  |  | CPH3225A |  | 1210 Seiko |  |  | None |  | https://www.snapeda.com/api/url_track_click_mouser/?unipart_id=562593&manufacturer=Seiko Instruments&part_name=CPH3225A&search_term=None |  | https://www.snapeda.com/parts/CPH3225A/Seiko+Instruments/view-part/?ref=snap
1 | DS3231SN# | DS3231SN# | SOIC127P1032X265-16N | U3 | Real Time Clock Serial 16-Pin SOIC W T/R Check availability |  |  | In Stock |  | https://www.snapeda.com/parts/DS3231SN%23/Analog+Devices/view-part/?ref=eda |  |  | Extremely Accurate I²C-Integrated RTC/TCXO/Crystal |  |  |  |  |  |  | Analog Devices |  |  |  |  |  | DS3231SN# |  | SOIC-16 Maxim |  |  | None |  | https://www.snapeda.com/api/url_track_click_mouser/?unipart_id=99048&manufacturer=Analog Devices&part_name=DS3231SN#&search_term=None |  | https://www.snapeda.com/parts/DS3231SN%23/Analog+Devices/view-part/?ref=snap
1 | ESP32-C6-WROOM-1-N8 | ESP32-C6-WROOM-1-N8 | XCVR_ESP32-C6-WROOM-1-N8 | U2 | Check availability |  |  | In Stock |  | https://www.snapeda.com/parts/ESP32-C6-WROOM-1-N8/Espressif+Systems/view-part/?ref=eda |  |  | Multiprotocol Modules ESP32-C6 module | Wi-Fi 6 in 2.4 GHz band | Bluetooth 5 | Zigbee 3.0 and Thread. ESP34-WROOM Compatible - ENGINEERING SAMPLE |  |  |  |  |  |  | Espressif Systems |  |  |  |  |  | ESP32-C6-WROOM-1-N8 |  | None |  |  | None |  |  |  | https://www.snapeda.com/parts/ESP32-C6-WROOM-1-N8/Espressif+Systems/view-part/?ref=snap
1 | ESP32C6_VARISTORCN1812 | ESP32C6_VARISTORCN1812 | ESP32C6_VARISTOR_CT/CN1812 | PFMF.050.1 | VARISTOR |  |  |  |  |  |  |  |  |  |  |  |  |  |  |  |  |  |  |  |  |  |  |  | 0
2 | ESP32_WROVER_AVX---SD0805S020S1R0_AVX_SD0805S020S1R0_0_0AVX_SD0805S020S1R0_0_0 | ESP32_WROVER_AVX---SD0805S020S1R0_AVX_SD0805S020S1R0_0_0AVX_SD0805S020S1R0_0_0 | ESP32_WROVER_AVX---SD0805S020S1R0_AVX_SD0805S020S1R0_0 | D2, D7 | Schottky Barrier Rectifier Diode |  |  |  | No |  |  | http://datasheets.avx.com/schottky.pdf |  | DIODE SCHOTTKY 20V 1A 0805 | 478-7800-1-ND |  | yes |  |  | AVX |  | 581-SD0805S020S1R0 |  |  |  |  |  | 0805 (2012 metric) |  | D |  |  |  | yes |  |  |  | +125°C | -55°C
1 | ESP32_WROVER_BME680_BME680 | ESP32_WROVER_BME680_BME680 | ESP32_WROVER_BME680_PSON80P300X300X100-8N | SENSOR2 | Integrated Environmental Unit |  |  | Unavailable |  |  |  |  | Integrated Environmental Unit |  |  |  |  |  |  | Bosch Sensortec |  |  |  |  |  | BME680 |  | LGA-8 Bosch Tools |  |  | None
1 | ESP32_WROVER_SPARKFUN-IC-POWER_MCP73831 | ESP32_WROVER_SPARKFUN-IC-POWER_MCP73831 | ESP32_WROVER_SPARKFUN-IC-POWER_SOT23-5 | U1 | MCP73831T Li-Ion, Li-Pol Controller |  |  |  |  |  |  |  |  |  |  |  |  |  |  |  |  |  |  |  |  |  |  |  |  |  |  | IC-09995
1 | FH34SRJ-24S-0.5SH_99_ | FH34SRJ-24S-0.5SH_99_ | FH34SRJ24S05SH99 | J1 | (0.50mm) Surface Mount, Right Angle |  |  |  |  |  |  |  | 24 Position FFC | FPC Connector Contacts | (0.50mm) Surface Mount | Right Angle |  |  | 1.1mm |  | Hirose | FH34SRJ-24S-0.5SH(99) |  |  | 798-FH34SRJ24S05SH99 | https://www.mouser.co.uk/ProductDetail/Hirose-Connector/FH34SRJ-24S-0.5SH99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
1 | MAX17048G+T10 | MAX17048G+T10 | SON50P200X200X80-9N | U4 | Check availability |  |  | In Stock |  | https://www.snapeda.com/parts/MAX17048G+T10/Analog+Devices/view-part/?ref=eda |  |  | 3µA 1-Cell/2-Cell Fuel Gauge with ModelGauge |  |  |  |  |  |  | Analog Devices |  |  |  |  |  | MAX17048G+T10 |  | TDFN-8 Maxim |  |  | None |  | https://www.snapeda.com/api/url_track_click_mouser/?unipart_id=329239&manufacturer=Analog Devices&part_name=MAX17048G+T10&search_term=None |  | https://www.snapeda.com/parts/MAX17048G+T10/Analog+Devices/view-part/?ref=snap
3 | MBR0530 | MBR0530 | ESP32_WROVER_AVX---SD0805S020S1R0_AVX_SD0805S020S1R0_0 | D3, D4, D5 | ON SEMICONDUCTOR - MBR0530 - DIODE, SCHOTTKY, 0.5A, 30V, SOD-123 |  |  | In Stock |  | https://www.snapeda.com/parts/MBR0530/Onsemi/view-part/?ref=eda |  |  | Diode Schottky 30 V 500mA Surface Mount SOD-123 |  |  |  |  |  |  | ON Semiconductor |  |  |  |  |  | MBR0530 |  | SOD-123-2 ON Semiconductor |  |  | None |  | https://www.snapeda.com/api/url_track_click_mouser/?unipart_id=179458&manufacturer=ON Semiconductor&part_name=MBR0530&search_term=None |  | https://www.snapeda.com/parts/MBR0530/Onsemi/view-part/?ref=snap
6 | PGB1010603MR | PGB1010603MR | DIOC1608X36N | D6, D8, D9, D10, D11, D12 | Check availability |  |  | In Stock |  | https://www.snapeda.com/parts/PGB1010603MR/Littelfuse/view-part/?ref=eda |  |  | 150V (Typ) Clamp - Ipp Tvs Diode Surface Mount 0603 (1608 Metric) |  |  |  |  |  |  | Littelfuse Inc. |  |  |  |  |  | PGB1010603MR |  | 0603 Littelfuse Inc. |  |  | None |  | https://www.snapeda.com/api/url_track_click_mouser/?unipart_id=5659453&manufacturer=Littelfuse Inc.&part_name=PGB1010603MR&search_term=None |  | https://www.snapeda.com/parts/PGB1010603MR/Littelfuse/view-part/?ref=snap
1 | QWIIC_RIGHT_ANGLE | QWIIC_CONNECTORJS-1MM | JST04_1MM_RA | J3 | SparkFun I2C Standard Qwiic Connector |  |  |  |  |  |  |  |  |  |  |  |  |  |  |  |  |  |  |  |  |  |  |  |  |  |  | CONN-13694 |  |  |  |  |  |  |  |  | QWIIC_RIGHT_ANGLE
1 | SAMACSYS_PARTS_USB4110-GF-A | SAMACSYS_PARTS_USB4110-GF-A | SAMACSYS_PARTS_USB4110GFA | J2 | CONN USB 2.0 TYPE-C R/A SMT |  |  |  |  |  |  |  | CONN USB 2.0 TYPE-C R/A SMT |  |  | 3.26mm |  | GCT (GLOBAL CONNECTOR TECHNOLOGY) | USB4110-GF-A |  |  | 640-USB4110-GF-A | https://www.mouser.co.uk/ProductDetail/GCT/USB4110-GF-A?qs=KUoIvG%2F9IlYiZvIXQjyJeA%3D%3D
1 | SI1308EDL-T1-GE3 | SI1308EDL-T1-GE3 | SOT65P210X110-3N | Q3 | MOSFET N-Ch 30V 1.5A TrenchFET SC70 Vishay Si1308EDL-T1-GE3 N-channel MOSFET Transistor, 1.5 A, 30 V, 3-Pin SC-70 |  |  | In Stock |  | https://www.snapeda.com/parts/SI1308EDL-T1-GE3/Vishay+Siliconix/view-part/?ref=eda |  |  | Si1308EDL-T1-GE3 N-channel MOSFET Transistor | 1.5 A | 30 V | 3-Pin SC-70 | Siliconix / Vishay SI1308EDL-T1-GE3 |  |  |  |  |  |  | Vishay Siliconix |  |  |  |  |  | SI1308EDL-T1-GE3 |  | SOT-323 Vishay Semiconductor |  |  | None |  | https://www.snapeda.com/api/url_track_click_mouser/?unipart_id=274603&manufacturer=Vishay Siliconix&part_name=SI1308EDL-T1-GE3&search_term=None |  | https://www.snapeda.com/parts/SI1308EDL-T1-GE3/Vishay+Siliconix/view-part/?ref=snap
17 | TPTP20R | TPTP20R | TP20R | 3V3_TP16, EPD_3V3_C_TP13, EPD_3V3_TP17, EPD_BUSY_TP9, EPD_CS_TP10, EPD_DC_TP11, EPD_RST_TP12, GND_TP4, GND_TP5, INT_RTC_TP15, MISO_TP6, MOSI_TP7, RX_TP2, SCK_TP8, TX_TP1, VBAT_TP3, VBUS_TP14 | Test pad |  |  |  |  |  |  |  |  |  |  |  |  |  |  |  |  |  |  |  |  |  |  |  | 2
1 | USBLC6-2SC6Y | USBLC6-2SC6Y | SOT95P280X145-6N | D1 | Low Cap. ESD Protection Auto SOT-23-6 STMicroelectronics USBLC6-2SC6Y, Dual Uni-Directional TVS Diode Array, 6-Pin SOT-23 |  |  | In Stock |  | https://www.snapeda.com/parts/USBLC6-2SC6Y/STMicroelectronics/view-part/?ref=eda |  |  | 17V Clamp 5A (8/20µs) Ipp Tvs Diode Surface Mount SOT-23-6 |  |  |  |  |  |  | STMicroelectronics |  |  |  |  |  | USBLC6-2SC6Y |  | SOT-23-6 STMicroelectronics |  |  | None |  |  |  | https://www.snapeda.com/parts/USBLC6-2SC6Y/STMicroelectronics/view-part/?ref=snap
1 | W25Q512JVEIQ | W25Q512JVEIQ | SON127P600X800X80-9N | U5 | Check availability |  |  | In Stock |  | https://www.snapeda.com/parts/W25Q512JVEIQ/Winbond+Electronics/view-part/?ref=eda |  |  | FLASH - NOR Memory IC 512Mb (64M x 8) SPI - Quad I/O 133 MHz 8-WSON (8x6) |  |  |  |  |  |  | Winbond Electronics |  |  |  |  |  | W25Q512JVEIQ |  | Package |  |  | None |  |  |  | https://www.snapeda.com/parts/W25Q512JVEIQ/Winbond+Electronics/view-part/?ref=snap
1 | XC6220A331MR-G | XC6220A331MR-G | SOT95P280X120-5N | IC4 | LDO Voltage Regulators |  |  |  |  |  |  |  | LDO Voltage Regulators |  |  | 1.2mm |  | Torex | XC6220A331MR-G |  |  | 865-XC6220A331MR-G | https://www.mouser.co.uk/ProductDetail/Torex-Semiconductor/XC6220A331MR-G?qs=AsjdqWjXhJ8ZSWznL1J0gg%3D%3D

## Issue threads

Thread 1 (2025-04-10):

[BUG] Intreruperi între planurile de masa de pe top/bottom in PCB 2D

StanciuVlad1, 2025-04-10:
Probleme observate:

- Planurile de top si bottom se intrerup in jurul componentei U2.

Impact:

- Masuratori incorecte sau coliziuni in model.

- Probleme de randare (artefacte) sau comportament neintentionat.

- Incalcarea specificatiilor de design.

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

mariaaliu, 2025-04-10:
Problemă rezolvată odată cu corectarea incompatibilității dintre fișierele `.brd` și `.fbrd`

În urma investigației, întreruperea planurilor de top și bottom în jurul componentei **U2** s-a dovedit a fi cauzată de aceeași incompatibilitate care a generat și erorile DRC din issue-ul anterior (#2).

După sincronizarea fișierelor și actualizarea layoutului în varianta _FIXED, planurile sunt acum continue și conforme cu așteptările.

Te rog să verifici și să confirmi dacă se poate închide issue-ul.

Closed 2025-04-10.

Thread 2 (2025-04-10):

[BUG] Erori la validarea DRC in componenta PCB-2D

StanciuVlad1, 2025-04-10:
Probleme observate:

- În fișierul de design PCB (BOARD_e_BOOK_READER__VERSIUNE_10_v44), mai multe fire (traces) generează erori la validarea DRC din cauza faptului că nu sunt incluse într-un net class care să aibă definită regula de lățime minimă de 0.15 mm.
- În total apar 9 erori (Copper Width și SMD) pe stratul Top (1).

Impact:

- Neconformitate cu specificatiile de design: Traseele care nu respecta regula de latime pot duce la comportament imprevizibil al circuitului sau la incompatibilitati cu alte parti ale designului.

- Risc de probleme electrice: O latime incorecta a traseului poate influenta capacitatea acestuia de a transporta curentul dorit in siguranta, afectand performanta sau fiabilitatea circuitului.

- Probleme la fabricatie: Producatorii de PCB-uri impun limite stricte privind latimea minima/maxima a traseelor. Abaterile pot duce la erori in procesul de fabricatie sau la respingerea placii.

Solutie propusa:

-  Crearea unui custom rule om care sa fie adaugata regula pentru net class-ul 'trasee alimentare' cu 0.15mm

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

Closed 2025-04-10.

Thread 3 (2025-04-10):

[Good Practice] Rutare inutila pe bottom intre L1 si C7

StanciuVlad1, 2025-04-10:
Problema observata:

- Conexiunea intre L1 si C7 a fost rutata pe stratul bottom in loc de top
- Traseul de pe top trece direct printre cele doua componente, cauzand aceasta problema

Impact:

- Risc crescut de interferente electromagnetice (EMI)

- Probleme potentiale de integritate a semnalului

- Posibile complicatii la fabricatie sau asamblare

Solutie sugerata:

- Rerutati conexiunea pe stratul top

- Verificati traseele adiacente pentru potentiale conflicte

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

mariaaliu, 2025-04-10:
### Actualizare: problemă remediată

Conexiunea dintre **L1** și **C7** a fost rerutată pe stratul **top**, eliminând trecerea inutilă pe stratul **bottom**.

#### Modificare efectuată:
- Traseul este acum direct pe stratul top, între cele două componente, conform sugestiei.
- Se evită interferențele EMI și se simplifică fabricația.

#### Dovadă:

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

---

Te rog să faci un **re-review** și să confirmi dacă modificarea este corectă și completă.

Mulțumesc!

Closed 2025-04-10.

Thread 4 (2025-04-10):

[BUG] Amplasare incorecta a componentei C10_SUPERCAP

StanciuVlad1, 2025-04-10:
Probleme observate:

- Componenta C10_Supercap este orientata gresit in design

- Trebuie rotita la 180° pentru a se potrivi cu schema electrica si cu modulul RTC S3231SN

Impact:

- Functie afectata: Poate cauza probleme la incarcarea supercondensatorului in modulul RTC

- Fabricatie: Riscuri la asamblare (componenta nu se va potrivi corect)

- Fiabilitate: Posibila defectare datorita polaritatii inverse

Solutie propusa:

- Rotiti C10_Supercap la 180° in layout

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

mariaaliu, 2025-04-10:
Am corectat orientarea componentei **C10_SUPERCAP** în fișierul `_FIXED`. Aceasta a fost rotită cu 180° pentru a corespunde schemei electrice și conectării corecte cu modulul RTC (DS3231SN).

### Dovada corecției este disponibilă în imaginea de mai jos:

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

Te rog să faci un **re-review** pentru a confirma că problema a fost rezolvată corect. Mulțumesc!

Closed 2025-04-10.

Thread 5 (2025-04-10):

[Improvement] O vizibilitate mai buna a Test Pad-urilor

StanciuVlad1, 2025-04-10:
Problema observata:

-   Lizibilitatea este scazuta pentru numele TP-urilor

Impact :

- Cresterea nivelului de dificultate in intelegerea schematicului

Solutie sugerata:

-  Micsorarea font-ului si reasezarea test pad-urilor

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

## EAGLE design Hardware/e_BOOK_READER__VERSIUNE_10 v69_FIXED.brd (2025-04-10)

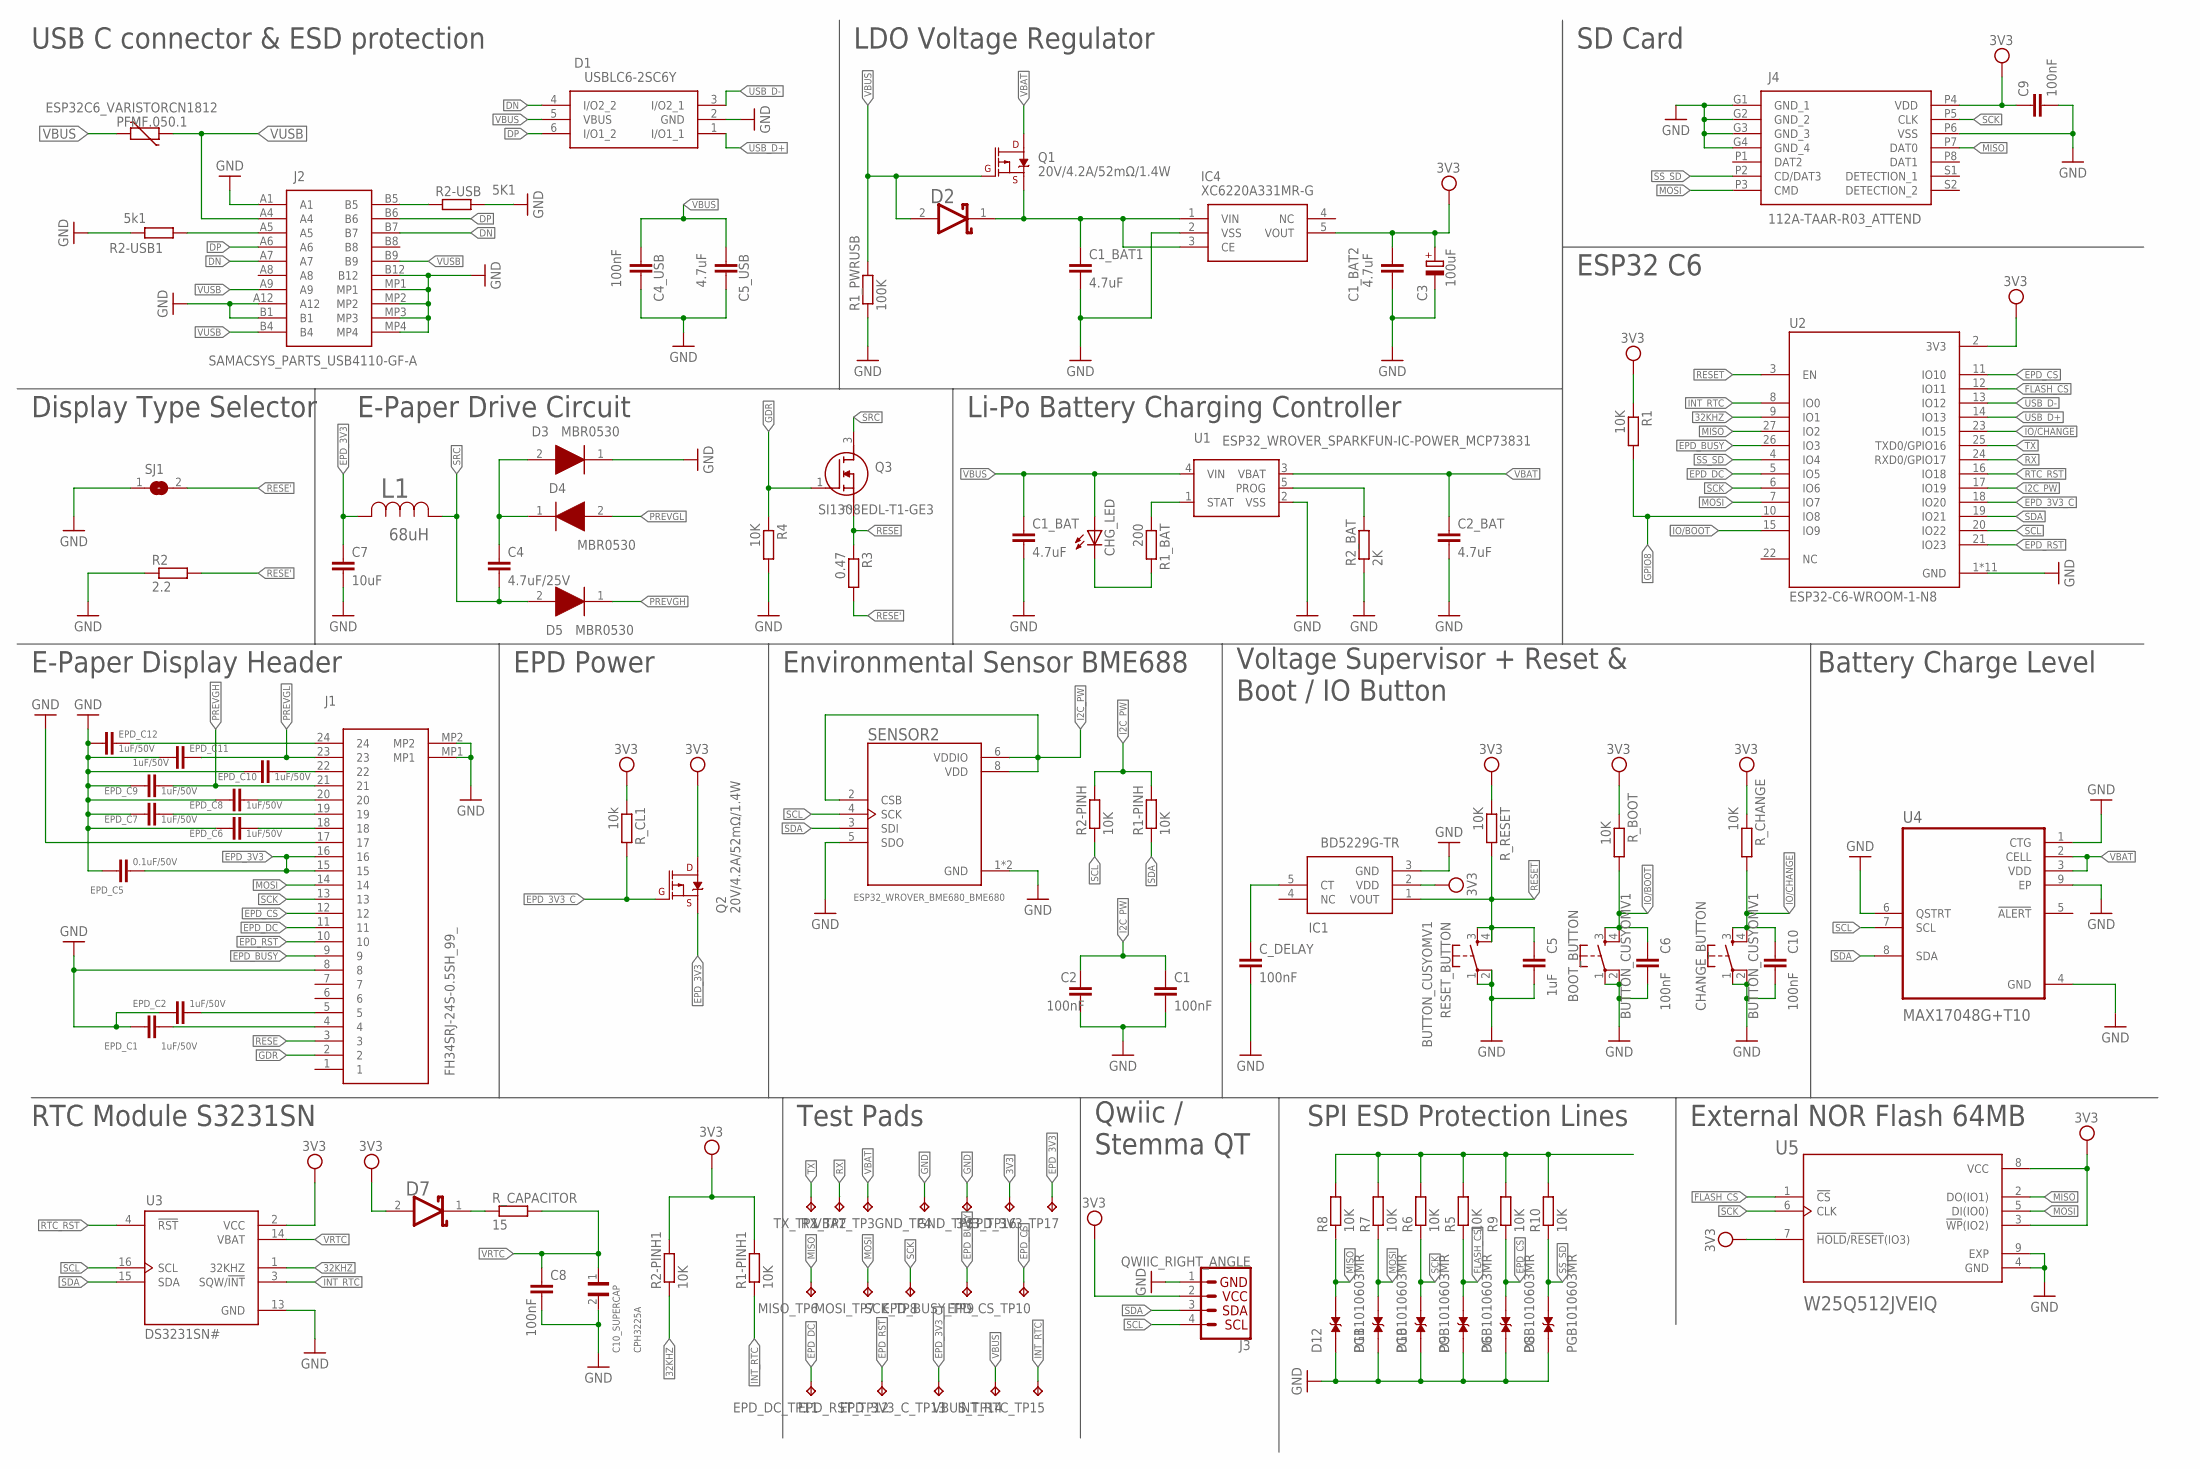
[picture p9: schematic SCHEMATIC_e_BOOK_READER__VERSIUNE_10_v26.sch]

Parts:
3V3_TP16: TPTP20R; TP20R
BOOT_BUTTON: BUTTON_CUSYOMV1; MYBUTTON
C1, C2, C4_USB, C6, C8, C9, C10: 100nF; ESP32_WROVER_EAGLE-LTSPICE_C0402
C1_BAT, C1_BAT1, C1_BAT2, C2_BAT, C5_USB: 4.7uF; ESP32_WROVER_EAGLE-LTSPICE_C0402
C3: 100uF; RCL_CT3528
C4: 4.7uF/25V; ESP32_WROVER_EAGLE-LTSPICE_C0402
C5: 1uF; ESP32_WROVER_EAGLE-LTSPICE_C0402
C7: 10uF; ESP32_WROVER_EAGLE-LTSPICE_C0402
C10_SUPERCAP: CPH3225A; CAPCP3225X100N
CHANGE_BUTTON: BUTTON_CUSYOMV1; MYBUTTON
CHG_LED: ADAFRUIT_LEDCHIP-LED0603; ADAFRUIT_CHIP-LED0603
C_DELAY: 100nF; ESP32_WROVER_EAGLE-LTSPICE_C0402
D1: USBLC6-2SC6Y; SOT95P280X145-6N
D2, D7: ESP32_WROVER_AVX---SD0805S020S1R0_AVX_SD0805S020S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; ESP32_WROVER_AVX---SD0805S020S1R0_AVX_SD0805S020S1R0_0
D3, D4, D5: MBR0530; ESP32_WROVER_AVX---SD0805S020S1R0_AVX_SD0805S020S1R0_0
D6, D8, D9, D10, D11, D12: PGB1010603MR; DIOC1608X36N
EPD_3V3_C_TP13, EPD_3V3_TP17: TPTP20R; TP20R
EPD_BUSY_TP9: TPTP20R; TP20R
EPD_C1, EPD_C2, EPD_C6, EPD_C7, EPD_C8, EPD_C9, EPD_C10, EPD_C11, EPD_C12: 1uF/50V; ESP32_WROVER_EAGLE-LTSPICE_C0402
EPD_C5: 0.1uF/50V; ESP32_WROVER_EAGLE-LTSPICE_C0402
EPD_CS_TP10: TPTP20R; TP20R
EPD_DC_TP11: TPTP20R; TP20R
EPD_RST_TP12: TPTP20R; TP20R
GND_TP4, GND_TP5: TPTP20R; TP20R
IC1: BD5229G-TR; SOT95P280X125-5N
IC4: XC6220A331MR-G; SOT95P280X120-5N
INT_RTC_TP15: TPTP20R; TP20R
J1: FH34SRJ-24S-0.5SH_99_; FH34SRJ24S05SH99
J2: SAMACSYS_PARTS_USB4110-GF-A; SAMACSYS_PARTS_USB4110GFA
J3: QWIIC_RIGHT_ANGLE; JST04_1MM_RA
J4: 112A-TAAR-R03_ATTEND; 112ATAARR03ATTEND
L1: 68uH; IND_4828-WE-TPC_WRE
MISO_TP6: TPTP20R; TP20R
MOSI_TP7: TPTP20R; TP20R
PFMF.050.1: ESP32C6_VARISTORCN1812; ESP32C6_VARISTOR_CT/CN1812
Q1, Q2: 20V/4.2A/52mΩ/1.4W; ESP32_WROVER_SPARKFUN-DISCRETESEMI_SOT23-3
Q3: SI1308EDL-T1-GE3; SOT65P210X110-3N
R1, R1-PINH, R1-PINH1, R2-PINH, R2-PINH1, R4, R5, R6, R7, R8, R9, R10: 10K; ESP32_WROVER_EAGLE-LTSPICE_R0402
R1_BAT: 200; ESP32_WROVER_EAGLE-LTSPICE_R0402
R1_PWRUSB: 100K; ESP32_WROVER_EAGLE-LTSPICE_R0402
R2: 2.2; ESP32_WROVER_EAGLE-LTSPICE_R0402
R2-USB: 5K1; ESP32_WROVER_EAGLE-LTSPICE_R0402
R2-USB1: 5k1; ESP32_WROVER_EAGLE-LTSPICE_R0402
R2_BAT: 2K; ESP32_WROVER_EAGLE-LTSPICE_R0402
R3: 0.47; ESP32_WROVER_EAGLE-LTSPICE_R0402
RESET_BUTTON: BUTTON_CUSYOMV1; MYBUTTON
RX_TP2: TPTP20R; TP20R
R_BOOT: 10K; ESP32_WROVER_EAGLE-LTSPICE_R0402
R_CAPACITOR: 15; ESP32_WROVER_EAGLE-LTSPICE_R0402
R_CHANGE: 10K; ESP32_WROVER_EAGLE-LTSPICE_R0402
R_CL1: 10k; ESP32_WROVER_EAGLE-LTSPICE_R0402
R_RESET: 10K; ESP32_WROVER_EAGLE-LTSPICE_R0402
SCK_TP8: TPTP20R; TP20R
SENSOR2: ESP32_WROVER_BME680_BME680; ESP32_WROVER_BME680_PSON80P300X300X100-8N
SJ1: SJ
TX_TP1: TPTP20R; TP20R
U1: ESP32_WROVER_SPARKFUN-IC-POWER_MCP73831; ESP32_WROVER_SPARKFUN-IC-POWER_SOT23-5
U2: ESP32-C6-WROOM-1-N8; XCVR_ESP32-C6-WROOM-1-N8
U3: DS3231SN#; SOIC127P1032X265-16N
U4: MAX17048G+T10; SON50P200X200X80-9N
U5: W25Q512JVEIQ; SON127P600X800X80-9N
VBAT_TP3: TPTP20R; TP20R
VBUS_TP14: TPTP20R; TP20R

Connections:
3V3: 3V3_TP16.TP, C1_BAT2.1, C3.+, C9.1, D7.2 (ANODE), IC1.2 (VDD), IC4.5 (VOUT), J3.2, J4.P4 (VDD), Q2.3 (D), R1.1, R1-PINH1.2, R2-PINH1.2, R_BOOT.1, R_CHANGE.1, R_CL1.1, R_RESET.1, U2.2 (3V3), U3.2 (VCC), U5.3 (!WP!(IO2)), U5.7 (!HOLD!/!RESET!(IO3)), U5.8 (VCC)
32KHZ: R2-PINH1.1, U2.9 (IO1), U3.1 (32KHZ)
DN: D1.4 (I/O2_2), J2.A7, J2.B7
DP: D1.6 (I/O1_2), J2.A6, J2.B6
EPD_3V3: C7.1, EPD_3V3_TP17.TP, EPD_C5.1, J1.15, J1.16, L1.2, Q2.2 (S)
EPD_3V3_C: EPD_3V3_C_TP13.TP, Q2.1 (G), R_CL1.2, U2.18 (IO20)
EPD_BUSY: EPD_BUSY_TP9.TP, J1.9, U2.26 (IO3)
EPD_CS: D6.2, EPD_CS_TP10.TP, J1.12, R9.1, U2.11 (IO10)
EPD_DC: EPD_DC_TP11.TP, J1.11, U2.5 (IO5)
EPD_RST: EPD_RST_TP12.TP, J1.10, U2.21 (IO23)
FLASH_CS: D9.2, R5.1, U2.12 (IO11), U5.1 (!CS)
GDR: J1.2, Q3.1 (G), R4.1
GPIO8: R1.2, U2.10 (IO8)
I2C_PW: C1.1, C2.1, R1-PINH.2, R2-PINH.2, SENSOR2.2 (CSB), SENSOR2.6 (VDDIO), SENSOR2.8 (VDD), U2.17 (IO19)
INT_RTC: INT_RTC_TP15.TP, R1-PINH1.1, U2.8 (IO0), U3.3 (SQW/!INT)
IO/BOOT: BOOT_BUTTON.3, BOOT_BUTTON.4, C6.1, R_BOOT.2, U2.15 (IO9)
IO/CHANGE: C10.1, CHANGE_BUTTON.3, CHANGE_BUTTON.4, R_CHANGE.2, U2.23 (IO15)
MISO: D12.2, J4.P7 (DAT0), MISO_TP6.TP, R8.1, U2.27 (IO2), U5.2 (DO(IO1))
MOSI: D11.2, J1.14, J4.P3 (CMD), MOSI_TP7.TP, R7.1, U2.7 (IO7), U5.5 (DI(IO0))
unnamed: C1_BAT1.1, D2.1 (CATHODE), IC4.1 (VIN), IC4.3 (CE), Q1.2 (S)
unnamed: J2.A5, R2-USB1.2
unnamed: R5.2, R6.2, R7.2, R8.2, R9.2, R10.2
unnamed: R1_BAT.1, U1.1 (STAT)
unnamed: C4.1, D3.2 (A), D4.1 (K)
unnamed: CHG_LED.C, R1_BAT.2
unnamed: D7.1 (CATHODE), R_CAPACITOR.1
unnamed: J2.B5, R2-USB.1
unnamed: C_DELAY.1, IC1.5 (CT)
unnamed: EPD_C12.1, J1.24
unnamed: R2_BAT.2, U1.5 (PROG)
unnamed: EPD_C8.1, J1.20
unnamed: EPD_C10.1, J1.22
unnamed: EPD_C7.1, J1.19
unnamed: EPD_C6.1, J1.18
unnamed: EPD_C1.1, J1.4
unnamed: EPD_C2.1, J1.5
PREVGH: D5.1 (K), EPD_C9.1, J1.21
PREVGL: D4.2 (A), EPD_C11.1, J1.23
RESE: J1.3, Q3.2 (S), R3.1
RESE': R2.2, R3.2, SJ1.2
RESET: C5.1, IC1.1 (VOUT), RESET_BUTTON.3, RESET_BUTTON.4, R_RESET.2, U2.3 (EN)
RTC_RST: U2.16 (IO18), U3.4 (!RST)
RX: RX_TP2.TP, U2.24 (RXD0/GPIO17)
SCK: D10.2, J1.13, J4.P5 (CLK), R6.1, SCK_TP8.TP, U2.6 (IO6), U5.6 (CLK)
SCL: J3.4, R2-PINH.1, SENSOR2.4 (SCK), U2.20 (IO22), U3.16 (SCL), U4.7 (SCL)
SDA: J3.3, R1-PINH.1, SENSOR2.3 (SDI), U2.19 (IO21), U3.15 (SDA), U4.8 (SDA)
SRC: C4.2, D5.2 (A), L1.1, Q3.3 (D)
SS_SD: D8.2, J4.P2 (CD/DAT3), R10.1, U2.4 (IO4)
TX: TX_TP1.TP, U2.25 (TXD0/GPIO16)
USB_D+: D1.1 (I/O1_1), U2.14 (IO13)
USB_D-: D1.3 (I/O2_1), U2.13 (IO12)
VBAT: C2_BAT.1, Q1.3 (D), U1.3 (VBAT), U4.2 (CELL), U4.3 (VDD), VBAT_TP3.TP
VBUS: C1_BAT.1, C4_USB.1, C5_USB.1, CHG_LED.A, D1.5 (VBUS), D2.2 (ANODE), PFMF.050.1.2, Q1.1 (G), R1_PWRUSB.2, U1.4 (VIN), VBUS_TP14.TP
VUSB: J2.A4, J2.A9, J2.B4, J2.B9, PFMF.050.1.1

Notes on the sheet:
USB C connector & ESD protection
LDO Voltage Regulator
SD Card
ESP32 C6
Display Type Selector
E-Paper Drive Circuit
Li-Po Battery Charging Controller
E-Paper Display Header
EPD Power
Environmental Sensor BME688
Voltage Supervisor + Reset & Boot / IO Button
Battery Charge Level
RTC Module S3231SN
Test Pads
Qwiic / Stemma QT
SPI ESD Protection Lines
External NOR Flash 64MB

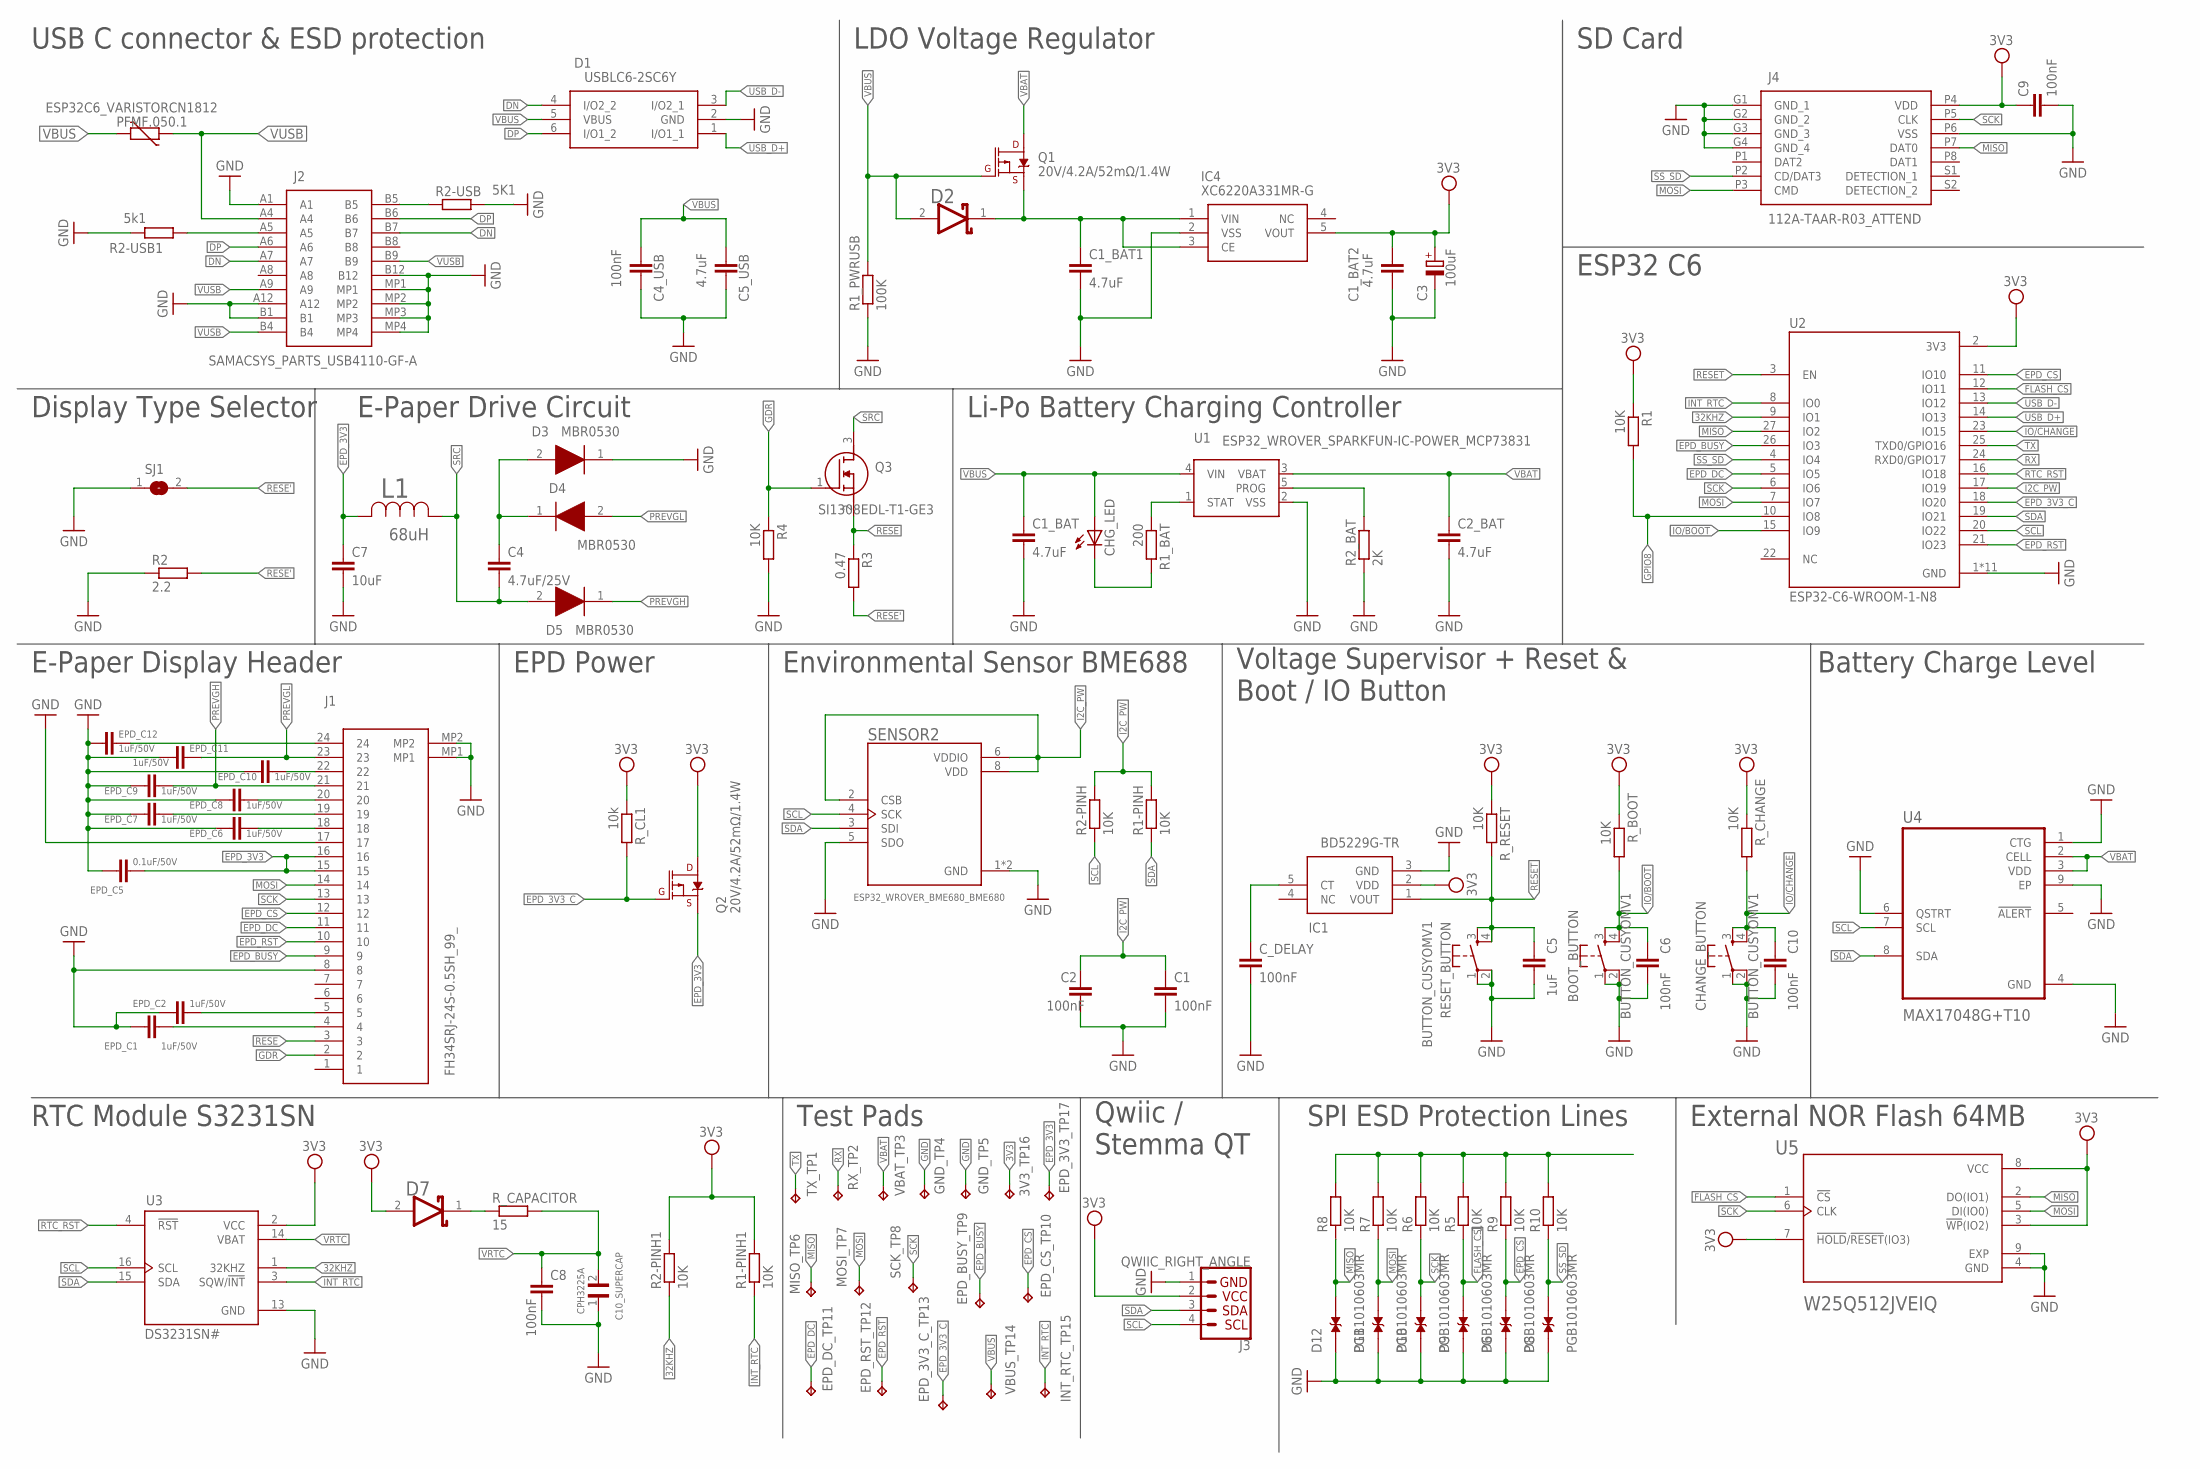
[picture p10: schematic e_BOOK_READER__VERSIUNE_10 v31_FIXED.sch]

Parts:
3V3_TP16: TPTP20R; TP20R
BOOT_BUTTON: BUTTON_CUSYOMV1; MYBUTTON
C1, C2, C4_USB, C6, C8, C9, C10: 100nF; ESP32_WROVER_EAGLE-LTSPICE_C0402
C1_BAT, C1_BAT1, C1_BAT2, C2_BAT, C5_USB: 4.7uF; ESP32_WROVER_EAGLE-LTSPICE_C0402
C3: 100uF; RCL_CT3528
C4: 4.7uF/25V; ESP32_WROVER_EAGLE-LTSPICE_C0402
C5: 1uF; ESP32_WROVER_EAGLE-LTSPICE_C0402
C7: 10uF; ESP32_WROVER_EAGLE-LTSPICE_C0402
C10_SUPERCAP: CPH3225A; CAPCP3225X100N
CHANGE_BUTTON: BUTTON_CUSYOMV1; MYBUTTON
CHG_LED: ADAFRUIT_LEDCHIP-LED0603; ADAFRUIT_CHIP-LED0603
C_DELAY: 100nF; ESP32_WROVER_EAGLE-LTSPICE_C0402
D1: USBLC6-2SC6Y; SOT95P280X145-6N
D2, D7: ESP32_WROVER_AVX---SD0805S020S1R0_AVX_SD0805S020S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; ESP32_WROVER_AVX---SD0805S020S1R0_AVX_SD0805S020S1R0_0
D3, D4, D5: MBR0530; ESP32_WROVER_AVX---SD0805S020S1R0_AVX_SD0805S020S1R0_0
D6, D8, D9, D10, D11, D12: PGB1010603MR; DIOC1608X36N
EPD_3V3_C_TP13, EPD_3V3_TP17: TPTP20R; TP20R
EPD_BUSY_TP9: TPTP20R; TP20R
EPD_C1, EPD_C2, EPD_C6, EPD_C7, EPD_C8, EPD_C9, EPD_C10, EPD_C11, EPD_C12: 1uF/50V; ESP32_WROVER_EAGLE-LTSPICE_C0402
EPD_C5: 0.1uF/50V; ESP32_WROVER_EAGLE-LTSPICE_C0402
EPD_CS_TP10: TPTP20R; TP20R
EPD_DC_TP11: TPTP20R; TP20R
EPD_RST_TP12: TPTP20R; TP20R
GND_TP4, GND_TP5: TPTP20R; TP20R
IC1: BD5229G-TR; SOT95P280X125-5N
IC4: XC6220A331MR-G; SOT95P280X120-5N
INT_RTC_TP15: TPTP20R; TP20R
J1: FH34SRJ-24S-0.5SH_99_; FH34SRJ24S05SH99
J2: SAMACSYS_PARTS_USB4110-GF-A; SAMACSYS_PARTS_USB4110GFA
J3: QWIIC_RIGHT_ANGLE; JST04_1MM_RA
J4: 112A-TAAR-R03_ATTEND; 112ATAARR03ATTEND
L1: 68uH; IND_4828-WE-TPC_WRE
MISO_TP6: TPTP20R; TP20R
MOSI_TP7: TPTP20R; TP20R
PFMF.050.1: ESP32C6_VARISTORCN1812; ESP32C6_VARISTOR_CT/CN1812
Q1, Q2: 20V/4.2A/52mΩ/1.4W; ESP32_WROVER_SPARKFUN-DISCRETESEMI_SOT23-3
Q3: SI1308EDL-T1-GE3; SOT65P210X110-3N
R1, R1-PINH, R1-PINH1, R2-PINH, R2-PINH1, R4, R5, R6, R7, R8, R9, R10: 10K; ESP32_WROVER_EAGLE-LTSPICE_R0402
R1_BAT: 200; ESP32_WROVER_EAGLE-LTSPICE_R0402
R1_PWRUSB: 100K; ESP32_WROVER_EAGLE-LTSPICE_R0402
R2: 2.2; ESP32_WROVER_EAGLE-LTSPICE_R0402
R2-USB: 5K1; ESP32_WROVER_EAGLE-LTSPICE_R0402
R2-USB1: 5k1; ESP32_WROVER_EAGLE-LTSPICE_R0402
R2_BAT: 2K; ESP32_WROVER_EAGLE-LTSPICE_R0402
R3: 0.47; ESP32_WROVER_EAGLE-LTSPICE_R0402
RESET_BUTTON: BUTTON_CUSYOMV1; MYBUTTON
RX_TP2: TPTP20R; TP20R
R_BOOT: 10K; ESP32_WROVER_EAGLE-LTSPICE_R0402
R_CAPACITOR: 15; ESP32_WROVER_EAGLE-LTSPICE_R0402
R_CHANGE: 10K; ESP32_WROVER_EAGLE-LTSPICE_R0402
R_CL1: 10k; ESP32_WROVER_EAGLE-LTSPICE_R0402
R_RESET: 10K; ESP32_WROVER_EAGLE-LTSPICE_R0402
SCK_TP8: TPTP20R; TP20R
SENSOR2: ESP32_WROVER_BME680_BME680; ESP32_WROVER_BME680_PSON80P300X300X100-8N
SJ1: SJ
TX_TP1: TPTP20R; TP20R
U1: ESP32_WROVER_SPARKFUN-IC-POWER_MCP73831; ESP32_WROVER_SPARKFUN-IC-POWER_SOT23-5
U2: ESP32-C6-WROOM-1-N8; XCVR_ESP32-C6-WROOM-1-N8
U3: DS3231SN#; SOIC127P1032X265-16N
U4: MAX17048G+T10; SON50P200X200X80-9N
U5: W25Q512JVEIQ; SON127P600X800X80-9N
VBAT_TP3: TPTP20R; TP20R
VBUS_TP14: TPTP20R; TP20R

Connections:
3V3: 3V3_TP16.TP, C1_BAT2.1, C3.+, C9.1, D7.2 (ANODE), IC1.2 (VDD), IC4.5 (VOUT), J3.2, J4.P4 (VDD), Q2.3 (D), R1.1, R1-PINH1.2, R2-PINH1.2, R_BOOT.1, R_CHANGE.1, R_CL1.1, R_RESET.1, U2.2 (3V3), U3.2 (VCC), U5.3 (!WP!(IO2)), U5.7 (!HOLD!/!RESET!(IO3)), U5.8 (VCC)
32KHZ: R2-PINH1.1, U2.9 (IO1), U3.1 (32KHZ)
DN: D1.4 (I/O2_2), J2.A7, J2.B7
DP: D1.6 (I/O1_2), J2.A6, J2.B6
EPD_3V3: C7.1, EPD_3V3_TP17.TP, EPD_C5.1, J1.15, J1.16, L1.2, Q2.2 (S)
EPD_3V3_C: EPD_3V3_C_TP13.TP, Q2.1 (G), R_CL1.2, U2.18 (IO20)
EPD_BUSY: EPD_BUSY_TP9.TP, J1.9, U2.26 (IO3)
EPD_CS: D6.2, EPD_CS_TP10.TP, J1.12, R9.1, U2.11 (IO10)
EPD_DC: EPD_DC_TP11.TP, J1.11, U2.5 (IO5)
EPD_RST: EPD_RST_TP12.TP, J1.10, U2.21 (IO23)
FLASH_CS: D9.2, R5.1, U2.12 (IO11), U5.1 (!CS)
GDR: J1.2, Q3.1 (G), R4.1
GPIO8: R1.2, U2.10 (IO8)
I2C_PW: C1.1, C2.1, R1-PINH.2, R2-PINH.2, SENSOR2.2 (CSB), SENSOR2.6 (VDDIO), SENSOR2.8 (VDD), U2.17 (IO19)
INT_RTC: INT_RTC_TP15.TP, R1-PINH1.1, U2.8 (IO0), U3.3 (SQW/!INT)
IO/BOOT: BOOT_BUTTON.3, BOOT_BUTTON.4, C6.1, R_BOOT.2, U2.15 (IO9)
IO/CHANGE: C10.1, CHANGE_BUTTON.3, CHANGE_BUTTON.4, R_CHANGE.2, U2.23 (IO15)
MISO: D12.2, J4.P7 (DAT0), MISO_TP6.TP, R8.1, U2.27 (IO2), U5.2 (DO(IO1))
MOSI: D11.2, J1.14, J4.P3 (CMD), MOSI_TP7.TP, R7.1, U2.7 (IO7), U5.5 (DI(IO0))
unnamed: C1_BAT1.1, D2.1 (CATHODE), IC4.1 (VIN), IC4.3 (CE), Q1.2 (S)
unnamed: J2.A5, R2-USB1.2
unnamed: R5.2, R6.2, R7.2, R8.2, R9.2, R10.2
unnamed: R1_BAT.1, U1.1 (STAT)
unnamed: C4.1, D3.2 (A), D4.1 (K)
unnamed: CHG_LED.C, R1_BAT.2
unnamed: D7.1 (CATHODE), R_CAPACITOR.1
unnamed: J2.B5, R2-USB.1
unnamed: C_DELAY.1, IC1.5 (CT)
unnamed: EPD_C12.1, J1.24
unnamed: R2_BAT.2, U1.5 (PROG)
unnamed: EPD_C8.1, J1.20
unnamed: EPD_C10.1, J1.22
unnamed: EPD_C7.1, J1.19
unnamed: EPD_C6.1, J1.18
unnamed: EPD_C1.1, J1.4
unnamed: EPD_C2.1, J1.5
PREVGH: D5.1 (K), EPD_C9.1, J1.21
PREVGL: D4.2 (A), EPD_C11.1, J1.23
RESE: J1.3, Q3.2 (S), R3.1
RESE': R2.2, R3.2, SJ1.2
RESET: C5.1, IC1.1 (VOUT), RESET_BUTTON.3, RESET_BUTTON.4, R_RESET.2, U2.3 (EN)
RTC_RST: U2.16 (IO18), U3.4 (!RST)
RX: RX_TP2.TP, U2.24 (RXD0/GPIO17)
SCK: D10.2, J1.13, J4.P5 (CLK), R6.1, SCK_TP8.TP, U2.6 (IO6), U5.6 (CLK)
SCL: J3.4, R2-PINH.1, SENSOR2.4 (SCK), U2.20 (IO22), U3.16 (SCL), U4.7 (SCL)
SDA: J3.3, R1-PINH.1, SENSOR2.3 (SDI), U2.19 (IO21), U3.15 (SDA), U4.8 (SDA)
SRC: C4.2, D5.2 (A), L1.1, Q3.3 (D)
SS_SD: D8.2, J4.P2 (CD/DAT3), R10.1, U2.4 (IO4)
TX: TX_TP1.TP, U2.25 (TXD0/GPIO16)
USB_D+: D1.1 (I/O1_1), U2.14 (IO13)
USB_D-: D1.3 (I/O2_1), U2.13 (IO12)
VBAT: C2_BAT.1, Q1.3 (D), U1.3 (VBAT), U4.2 (CELL), U4.3 (VDD), VBAT_TP3.TP
VBUS: C1_BAT.1, C4_USB.1, C5_USB.1, CHG_LED.A, D1.5 (VBUS), D2.2 (ANODE), PFMF.050.1.2, Q1.1 (G), R1_PWRUSB.2, U1.4 (VIN), VBUS_TP14.TP
VUSB: J2.A4, J2.A9, J2.B4, J2.B9, PFMF.050.1.1

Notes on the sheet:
USB C connector & ESD protection
LDO Voltage Regulator
SD Card
ESP32 C6
Display Type Selector
E-Paper Drive Circuit
Li-Po Battery Charging Controller
E-Paper Display Header
EPD Power
Environmental Sensor BME688
Voltage Supervisor + Reset & Boot / IO Button
Battery Charge Level
RTC Module S3231SN
Test Pads
Qwiic / Stemma QT
SPI ESD Protection Lines
External NOR Flash 64MB

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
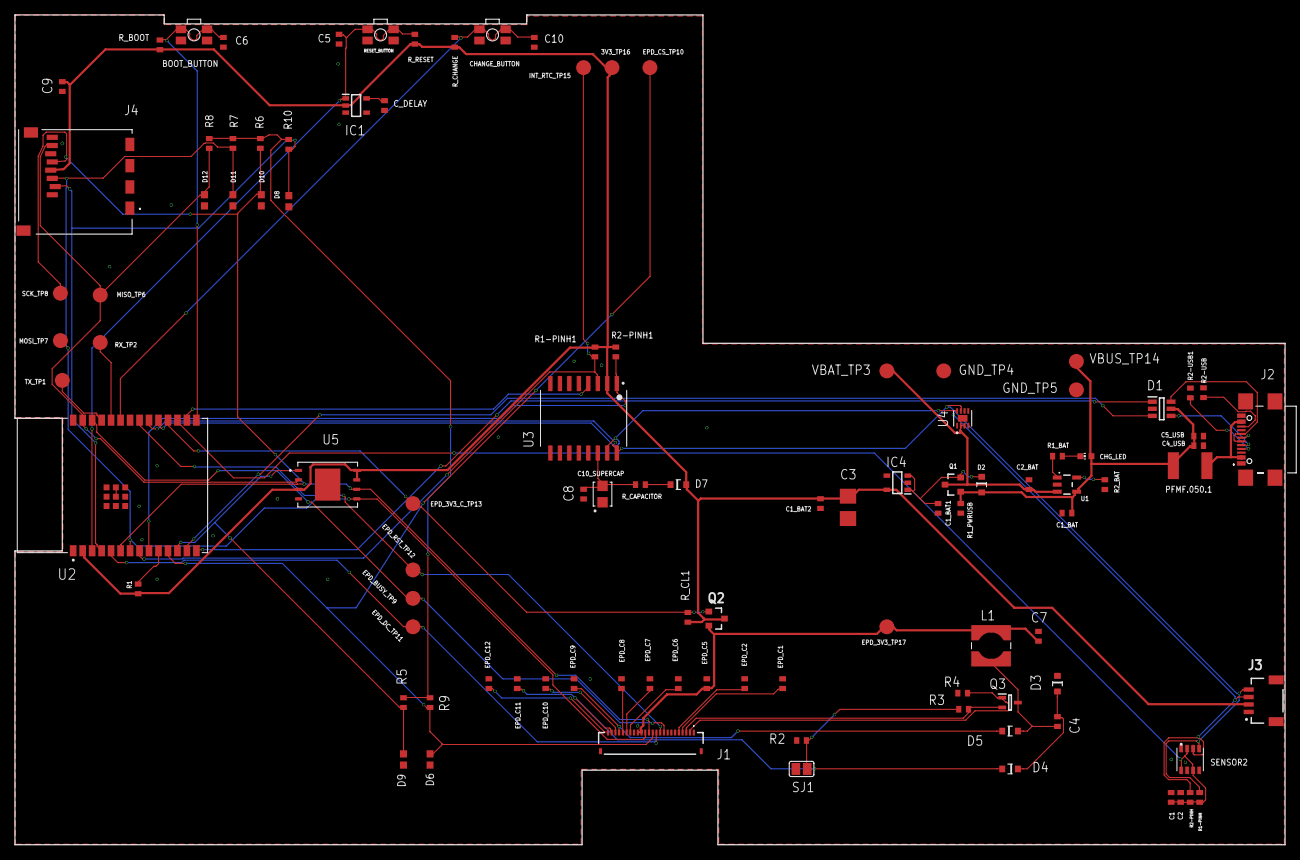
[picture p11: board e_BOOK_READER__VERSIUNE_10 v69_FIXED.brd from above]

Board: 2 copper layers, 170.2 x 111.2 mm, 103 parts (0 on the bottom side), 56 nets.

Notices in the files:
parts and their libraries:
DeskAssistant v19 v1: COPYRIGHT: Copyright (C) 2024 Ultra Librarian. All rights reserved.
